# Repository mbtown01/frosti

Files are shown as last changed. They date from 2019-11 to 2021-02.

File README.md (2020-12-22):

# FROSTI

FROSTI (the Financially Responsive Open-Source Thermostat Initiative) is a
Raspberry Pi-based thermostat that monitors the current price of power on
the electric grid and changes temperature targets to minimize power usage 
during periods of high prices.

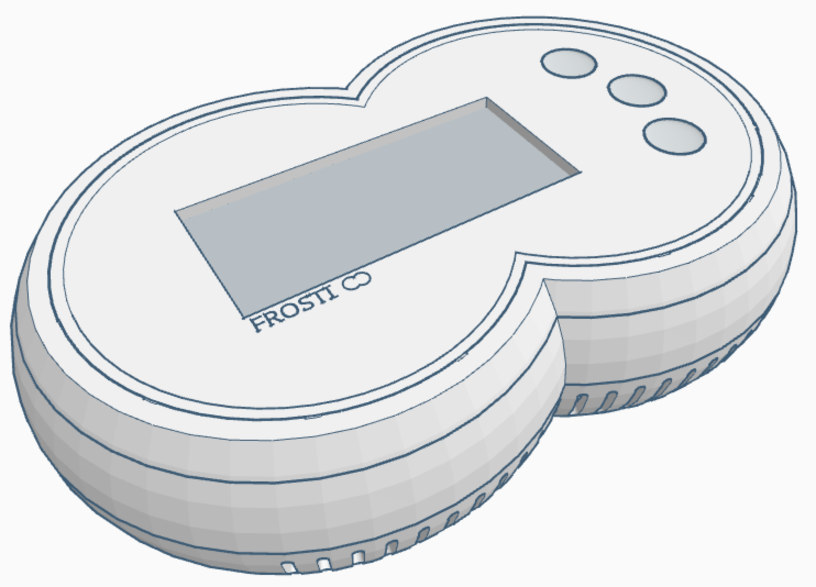
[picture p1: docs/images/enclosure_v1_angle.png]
rendering


## Features

* Real-time monitoring of local power-price
* Web-based configuration
* 2.9" e-paper display clearly visible from a distance
* LED indicators for mode changes
* Full RESTful API for monitoring status and controlling from remote

## Links

[FROSTI main site](https://mbtown01.github.io/frosti/)

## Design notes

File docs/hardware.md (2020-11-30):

---
layout: post
title: Hardware
---

At the heart of this project is the circuity that attaches to the
Raspberry Pi and hosts the extra elements that make the thermostat work.

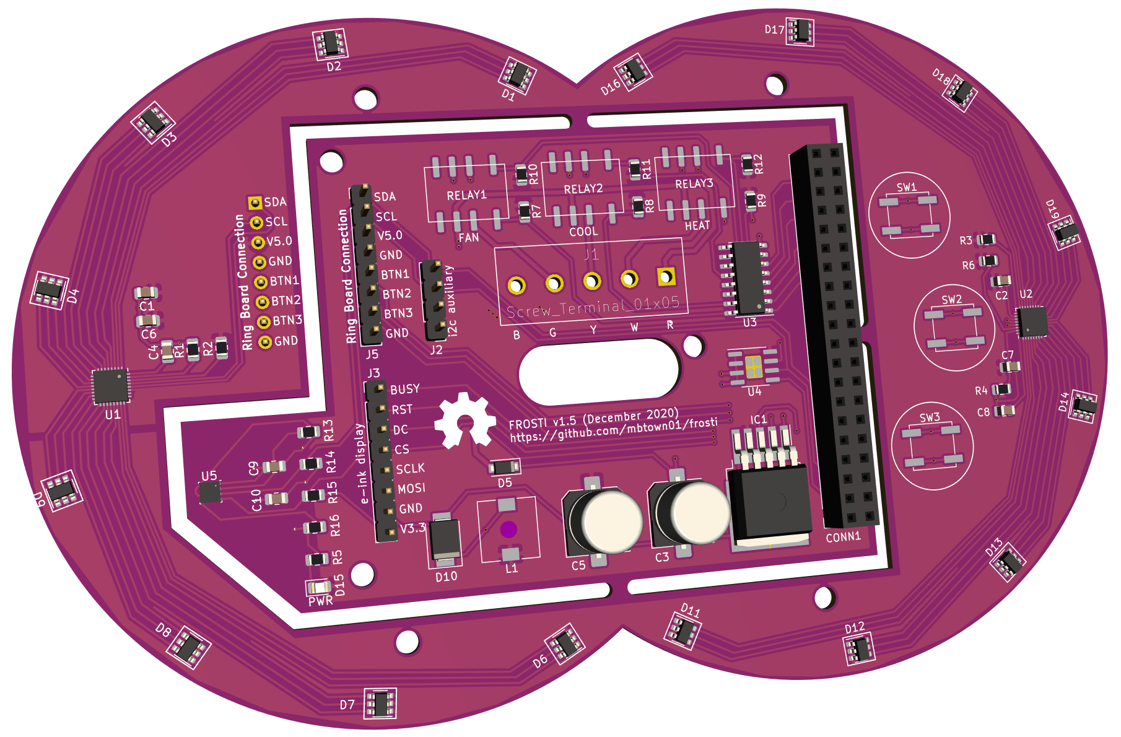
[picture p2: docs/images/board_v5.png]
board v5 rendering


The board integrates the following components:

* 24V AC to 5V DC transformer circuit
* Relays for A/C, heat and fan (simple 5-wire)
* Header for the e-paper display (Waveshare 2.9" with partial update)
* Two partial rings of 8 multi-color LEDs, each controlled w/ an LP5024
  LED driver chip for high-frequency dimming and color mixing
* BME280 environment sensor, capturing temperature, pressure and humidity
* A CAT24C256 for i2c-based storage (a component I have some ideas for
  but honestly have no clue for sure what I'll do with!)

The board is actually two boards, that after being assmebled are detached and
installed in different locations.

## Main Board

Internally there are two PCBs -- the main board containing the power
conversion circuit, thermostat relays, and the Raspberry Pi header.  It 
also contains the environment sensor, which may need to be relocated depending
on the thermals inside the case.

### Thermostat connection

FROSTI runs on the standard "5-wire" thermostat configuration, with the
following connections:

* Blue -- Common ground
* Green -- Return to power **fan**
* Yellow -- Return to power **A/C**
* White -- Return to power **heat**
* Red -- Thermostat 24V power input

The main board has a 5-port screw terminal, with the 1st letter of the wire
color labeled for installation.  

## Ring Board

The ring board is a breakout board containing all the LEDs for the UI.

This transparent rendering will give a feel for what the insides look like.

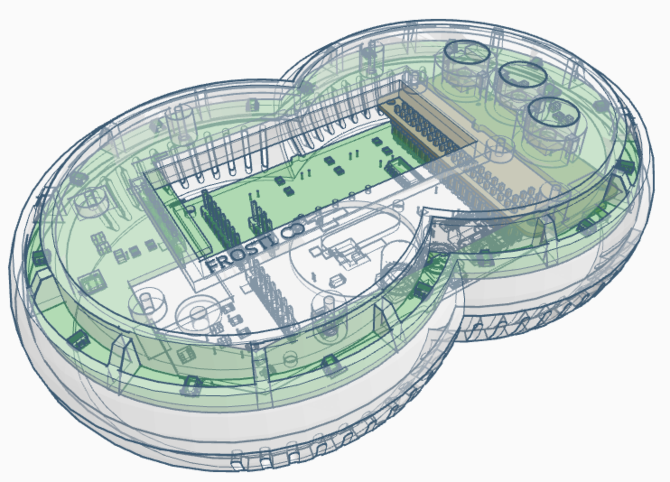
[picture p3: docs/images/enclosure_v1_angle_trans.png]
rendering


## Credits

I'd like to thank  Rays Hobby for a [great write-up on 24V AC to 5V DC power
conversion](https://rayshobby.net/wordpress/24vac-to-5vdc-conversion/).  I
personally run Ray's [OpenSprinkler Pi (OSPi)
platform](https://opensprinkler.com/product/opensprinkler-pi/) (with the 8-zone
extender!) and was inspired to take a shot at my own board by reading his blog
posts.

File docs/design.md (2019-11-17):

# Design

I kicked the idea of building a simple thermostat around for a few years.  My first iteration was a C++/Qt thermostat with a nice LCD touchscreen.  But since the RaspberryPi isn't the best _development_ environment, that quickly turned into a rabbit hole of C++ cross-compiling and libc compatibility, and don't get me started on the LCD display.

Picking the project up again in September, I took a more 'agile' approach and embraced an MVP that had a working hardware/software combination to get something *working*!  From there, we can refine.  So with that in mind, I started over in python.

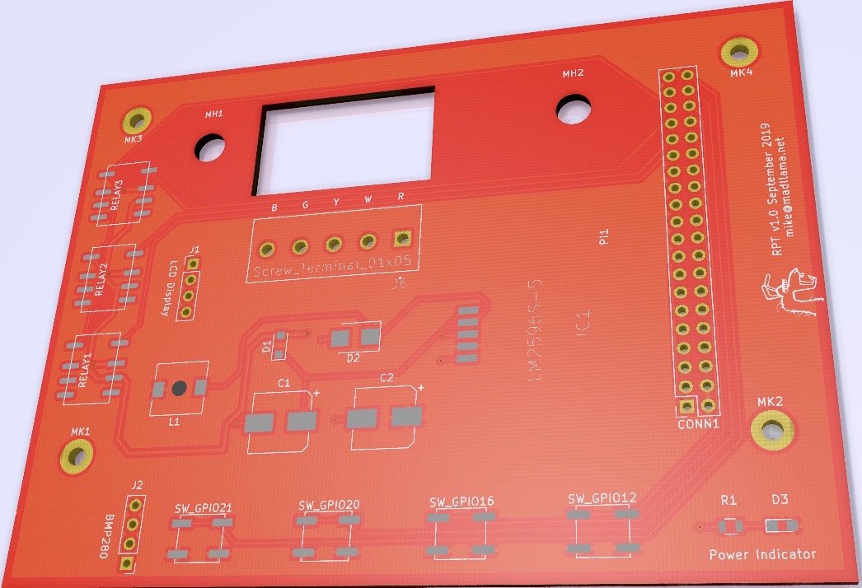
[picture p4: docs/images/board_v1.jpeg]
RPT board v1.0 rendering


The board is very simple, integrating:
* 24V AC to 5V DC power conversion
* RaspberryPi Zero W
* Three independent relays (cooling, heating, and fan)
* 20x4 character-based LCD
* 5-way temminal block to host the 5-wire thermostat cable
* 4 buttons for user input
* 2 I2C headers for the temperature sensor (BMP280) and the LCD

This is board v1.0, and there are many things that absolutely need to be changed.  I intend on writing an entire article on what I learned by running this board for a period of time and what will go into v2.0.

I'd like to thank Ray at Rays Hobby for a [great write-up on 24V AC to 5V DC power conversion](https://rayshobby.net/wordpress/24vac-to-5vdc-conversion/).  I personally run Ray's [OpenSprinkler Pi (OSPi) platform](https://opensprinkler.com/product/opensprinkler-pi/) (with the 8-zone extender!) and was inspired to take a shot at my own board by reading his blog posts.

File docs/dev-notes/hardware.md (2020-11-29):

# Hardware notes

## Simulator for Relays

After a few mis-steps, I learned that you need to give the relays more power
to move than GPIO is able to deliver.  We're employing a 'Darlington array'
(the TI ULN2003AD chip) to *briefly* deliver about 95mW to the relay.

The code below can be pasted into the circuit simulator at
<https://www.falstad.com/circuit/> to simulate the relay circuit.  The resistors
we're using (Mouser part 667-ERJ-P06F64R9V) can dissipate up to 500mW, which
this circuit will get to about 80% to move the relay.  In code, we ensure this
loop is only active for a fraction of a second.

```
$ 1 0.000005 10.20027730826997 50 5 43
r 368 272 368 160 0 64
r 224 272 224 160 0 64
r 368 272 224 272 0 90
w 224 160 368 160 0
v 128 352 128 160 0 0 40 5 0 0 0.5
w 128 160 224 160 0
s 224 272 224 352 0 1 false
s 368 272 368 352 0 1 false
w 128 352 224 352 0
w 224 352 368 352 0
```

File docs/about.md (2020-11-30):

---
layout: page
title: About
permalink: /about/
---

FROSTI (the Financially Responsive Open-Source Thermostat Initiative) is a
Raspberry Pi-based thermostat that monitors the local spot market for power
and changes temperature targets to minimize power usage during periods of
high prices.

rendering

## Features

* Real-time monitoring of local power-price
* Web-based configuration
* 2.9" e-paper display clearly visible from a distance
* LED indicators for mode changes
* Full RESTful API for monitoring status and controlling from remote

Today, FROSTI works with [GoGriddy](https://www.gogriddy.com/), but can
be extended in the future for other power markets.

## Motivation

I love the idea of having electricity priced based on supply/demand. It wasn't
long after a few friends told me about [GoGriddy](https://www.gogriddy.com/)
that I signed up.  Starting in January of 2019, I was easily saving 20% or so
relative to available electricy plans. Everything was going according to plan.

Then in August of 2019, Houston (where I live) experienced record heat combined
with electricity generation capacity shortages, causing massive spikes in
prices.  There were several times that month where prices got to $9/kW\*h,
costing me around $100 in a *single hour*.

My motivation is very simple.  Air conditioning is by far my biggest source
of power consumption.  If I can curtail usage during periods of high prices,
I get the benefits of cheap power 99.95% of the time and de-risk the other
0.05%, and I come out a winner.

## Future Work

FROSTI is about far more than just lowering your power bills.  The *data* that
comes from FROSTI is valuable for things like:

* Sizing a next A/C system (e.g. how many 'tons')
* Knowing whether your A/C system is
  [short-cycling](https://www.google.com/search?q=what+is+short+cycling)
* Knowing how changing your temperature targets affects HVAC usage

Also, with the addition of remote sensors, we could do things like:

* Balance HVAC for additional rooms
* Monitor the temperature of air coming out of the ducts, potentially catching
  problems
* Monitor the air speed at the ducts, potentially notifying the homeowner that
  airflow is impeded (e.g. filter needs changed)

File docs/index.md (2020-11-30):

---
# Feel free to add content and custom Front Matter to this file.
# To modify the layout, see https://jekyllrb.com/docs/themes/#overriding-theme-defaults
layout: home
---

FROSTI (the Financially Responsive Open-Source Thermostat Initiative) is a
Raspberry Pi-based thermostat that monitors the local spot market for power
and changes temperature targets to minimize power usage during periods of
high prices.

Today, FROSTI only works with [GoGriddy](https://www.gogriddy.com/), but can
be extended in the future for other markets where end-users are billed.

rendering

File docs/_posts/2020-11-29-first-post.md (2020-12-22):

---
layout: post
title:  "Progress towards hardware v1.5"
date:   2020-11-28 07:29:48 -0500
categories: update
---

This project has been going on in some form since the summer of 2019, and I'm
now finally getting around to blogging about it.  My goal here is to
keep some kind of a history of issues encountered and overcome, as well as
technology choices (and how that choice panned out!)

My main has recently been finalizing hardware v1.5 and an enclosure (latest
rendering below)

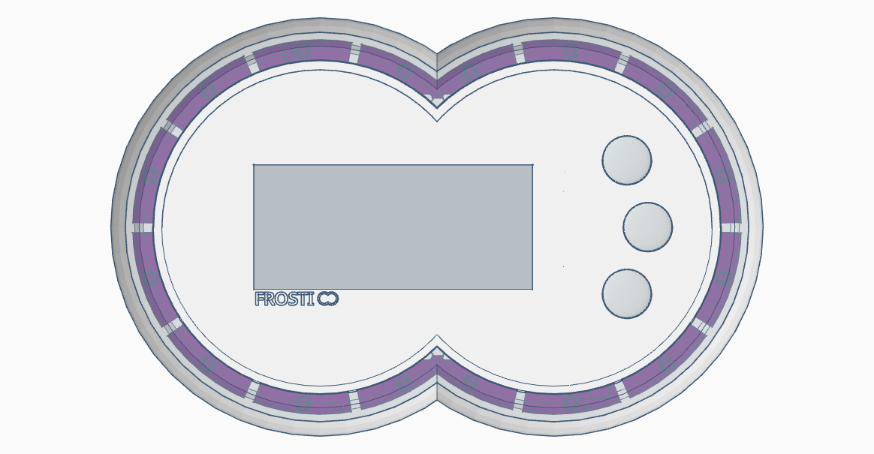
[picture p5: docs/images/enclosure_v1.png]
enclosure v1 rendering


The main (gray) rectangle outlines the location of the e-paper display I'll
be using for general status, and the three gray circles are buttons.  The
purple ring is actually the PCB visible through what will eventually be
a separately printed *translucent* cover that will scatter the light coming
from the 16 LEDs (8 in each ring) used for status indication.

The actual PCB I put together (which is as close to [OSHPark](http://oshpark.com)
purple I could get!) is below

board v5 rendering

Included in hardware v5 will be:

* 24V AC to 5V DC transformer circuit
* Relays for A/C, heat and fan (simple 5-wire)
* Header for the e-paper display (Waveshare 2.9" with partial update)
* Two partial rings of 8 multi-color LEDs, each controlled w/ an LP5024
  LED driver chip for high-frequency dimming and color mixing
* BME280 environment sensor, capturing temperature, pressure and humidity
* A CAT24C256 for i2c-based storage (a component I have some ideas for
  but honestly have no clue for sure what I'll do with!)

## Next steps

I have ordered a PRUSA "mini" 3d printer and it should be arriving in the
next week or two.  You can be sure I'll have several updates on what I learn
as part of doing some of my first 3d prints!

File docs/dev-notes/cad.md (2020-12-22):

# CAD and 3d Printing

Some references I've found on the web that are helpful when designing the
case:

* <https://ultimaker.com/en/resources/52843-design-guidelines>

## KiCAD tips/tricks

Export a BOM for Mouser

* Use the bom2grouped_csv plugin
* cut -d, -f2,7 thermostat | sed "s/\"//g" | grep -v "^[0-9],*$" | grep -v MPN | sed "s/\(.*\),\(.*\)/\2 \1/"
* Use mouser's BOM import tool, paste in the text generated above

## Looking at both board and model simultaneously

* Export as VRML (with mm as units) from Kicad
* Use <https://www.makexyz.com/convert/wrl-to-stl> to convert to STL
* Import directly into Tinkercad

## Tips and tricks for 3d design of printed parts

* <https://www.3dhubs.com/knowledge-base/enclosure-design-3d-printing-step-step-guide/>
* <http://infocenter.3dsystems.com/bestpractices/mjp-best-practices/projet-mjp-2500/snap-fits>

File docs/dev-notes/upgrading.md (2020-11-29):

# Upgrading the thermostat

```bash
# Upgrade docker-compose
sudo pip uninstall docker-compose
sudo pip install docker-compose
```

```bash
# Pull the latest images
docker-compose --file docker/docker-compose-arm.yaml pull
```

You may want to backup the database as well

sudo systemctl daemon-reload
/etc/systemd/system/frosti.service

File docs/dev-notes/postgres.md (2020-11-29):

# Working with postgres

## Get some data for development work

The scenario is that you have a thermostat in production and want to grab some
data from it to use locally. First, get a terminal in the postgres container:

```bash
docker exec -ti frosti-daemon bash
```

From there, grab the data from the running thermostat you're interested in and
place it in the local docker-compose postgres instance 'postgres':

```bash
# Extract info from a specific thermostat
pg_dump --host pi-frosti-h1.local.madllama.net \
    --username frosti frosti \
    --create --schema=public --clean  > /tmp/dump.dat
# Drop the existing schema if it exists
psql \
    --host postgres \
    --command='drop schema public cascade' frosti frosti
# Import the data AND SCHEMA
psql \
    --host postgres \
    --file /tmp/dump.dat frosti frosti
```

## Upgrading schemas

When a non-trivial change to the postgres schema happens, I've created an
'upgrade-db.py' script to facilitate things outside the normal execution
path of the thermostat logic. It simply moves the existing schema over to
another name and does internal SELECT INTO statements to massage the data
and populate the new schema.

```bash
PYTHONPATH=. ./scripts/upgrade-db.py --finalize
```

## Fun queries

Process the thermostat state log and show event durations

```sql
select
    time as endingTime,
    delta,
    delta*lastCooling as coolingSeconds,
    delta*lastHeating as heatingSeconds,
    delta*lastFan as fanSeconds
from (
    select
        time,
        lag(cooling) over (order by time) as lastCooling,
        lag(heating) over (order by time) as lastHeating,
        lag(fan) over (order by time) as lastFan,
        extract(epoch from time-lag(time) over (order by time)) as delta
    from thermostat_state
    ) as foo
```

Show how many times the thermostat skipped a reasonably
long temperature check over the past 30 days, possibly 
because it had frozen and needed a reboot
```sql
select
    *
from (
    select
        time, time - lag(time) over (order by time) as delta
    from sensor_reading
    where time > NOW() - INTERVAL '30 DAYS'
    ) as foo
where extract(epoch from foo.delta) > 60
```

Calculate the percentage of time we spend cooling over the past 24 hours

```sql
select
    NOW() as time, sum(delta*lastCooling)/3600.0/24.0 as percentCooling
from (
    select
        lag(cooling) over (order by time) as lastCooling,
        extract(epoch from time-lag(time) over (order by time)) as delta
    from thermostat_state
    where time > NOW() - INTERVAL '1 DAY'
    ) as foo
```

Calculate the percentage of time we spend cooling over the past 24 hours

```sql
select
    min(foo.time) as time, avg(foo.delta)/60.0 as "average cycle time"
from (
    select
        time,
        lag(cooling) over (order by time) as lastCooling,
        lag(heating) over (order by time) as lastHeating,
        extract(epoch from time-lag(time) over (order by time)) as delta
    from thermostat_state
    ) as foo
where
  foo.time BETWEEN '2020-05-20T15:26:45.498Z' AND '2020-05-20T18:26:45.498Z'
  and lastCooling + lastHeating > 0
group by
  floor(extract(epoch from foo.time)/60)*60
```

Old query grouping by minute that AVERAGES when we really want LAST_VALUE

```sql
SELECT
  floor(extract(epoch from "time")/60)*60 AS "time",
  max(comfort_max) AS "comfort_max"
FROM thermostat_targets
WHERE
  "time" BETWEEN '2020-05-19T18:53:14.694Z' AND '2020-05-20T18:53:14.694Z'
GROUP BY 1
ORDER BY 1
```

New query

```sql
select
    floor(extract(epoch from bar.time)/60)*60 AS "time",
    max(bar.comfort_max) AS "comfort_max"
from (
    select
        time,
        last_value(comfort_max)
        over (
            partition by floor(extract(epoch from time)/60)*60
            order by time
            range between unbounded preceding and unbounded following
        ) comfort_max
    from
        thermostat_targets
    union
    select
        '2020-05-20T08:20:33.914Z' as time,
        last_value(comfort_max)
        over (
            order by time
            range between unbounded preceding and unbounded following
        ) comfort_max
    from
        thermostat_targets
    WHERE
        "time" < '2020-05-20T08:20:33.914Z'
) bar
WHERE
    "time" BETWEEN '2020-05-20T08:20:33.914Z' AND '2020-05-20T20:20:33.914Z'
GROUP BY 1
ORDER BY 1
```

```sql
select
    NOW() as time,
    avg(delta*lastCooling)/60.0 as "average cycle time"
from (
    select
        lag(cooling) over (order by time) as lastCooling,
        extract(epoch from time-lag(time) over (order by time)) as delta
    from thermostat_state
    ) as foo
where
    lastCooling > 0
```

```sql
select
    measurement, bucket, count(bucket)
from (
    select
        NOW() as time,
        measurement,
        round(delta*value/60)*1 as bucket
    from (
        select
            'cooling' as measurement,
            lag(cooling) over (order by time) as value,
            extract(epoch from time-lag(time) over (order by time)) as delta
        from thermostat_state
        where time > NOW() - INTERVAL '1 DAY'
        union
        select
            'heating' as measurement,
            lag(heating) over (order by time) as value,
            extract(epoch from time-lag(time) over (order by time)) as delta
        from thermostat_state
        where time > NOW() - INTERVAL '1 DAY'
        ) as foo
    where
        value > 0
) as bar
group by
    measurement, bucket
order by
    bucket
```

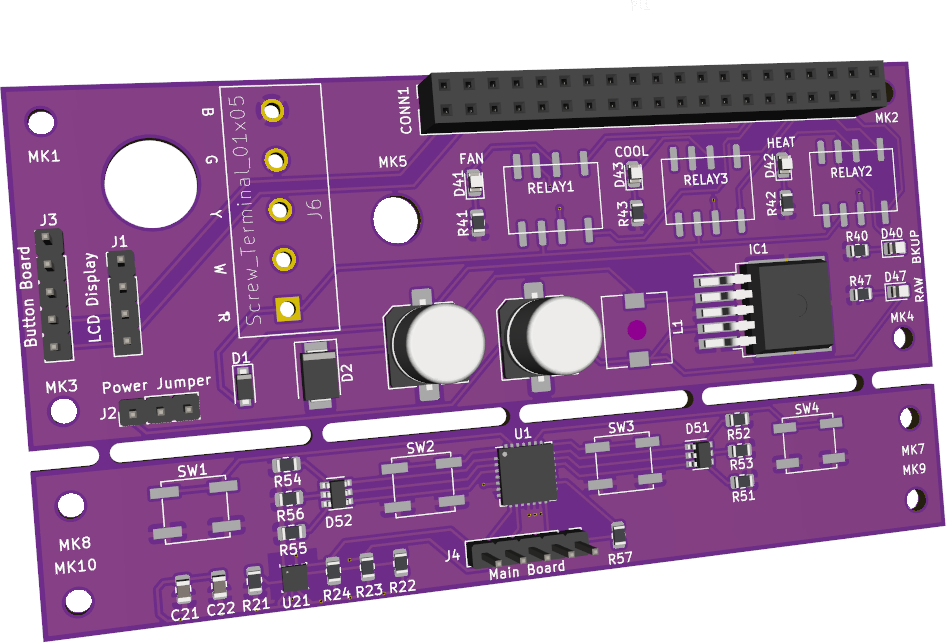
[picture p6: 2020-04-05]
docs/images/board_v4.png

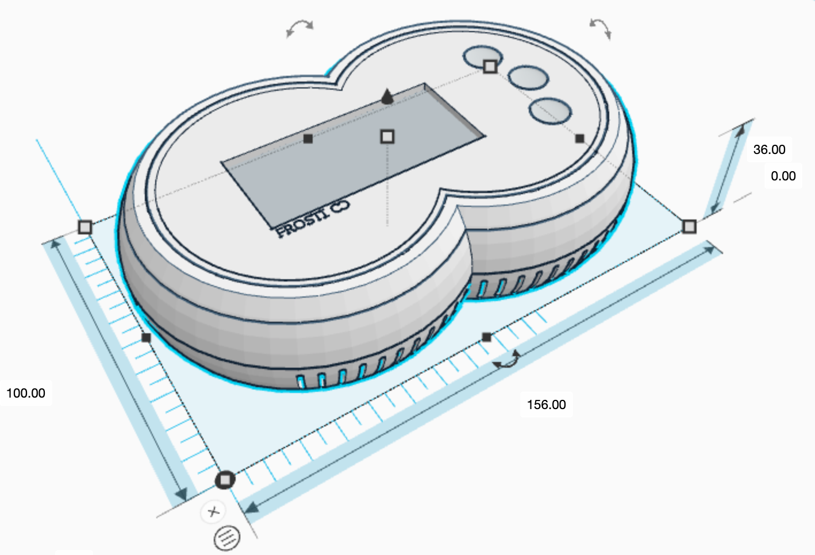
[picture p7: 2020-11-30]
docs/images/enclosure_v1_dimensions.png

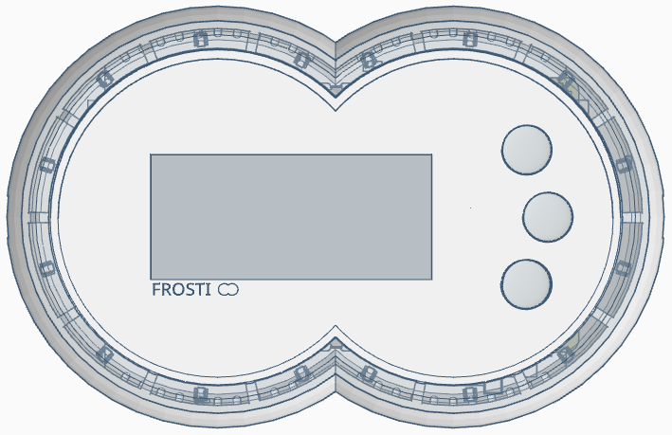
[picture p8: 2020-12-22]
front.png

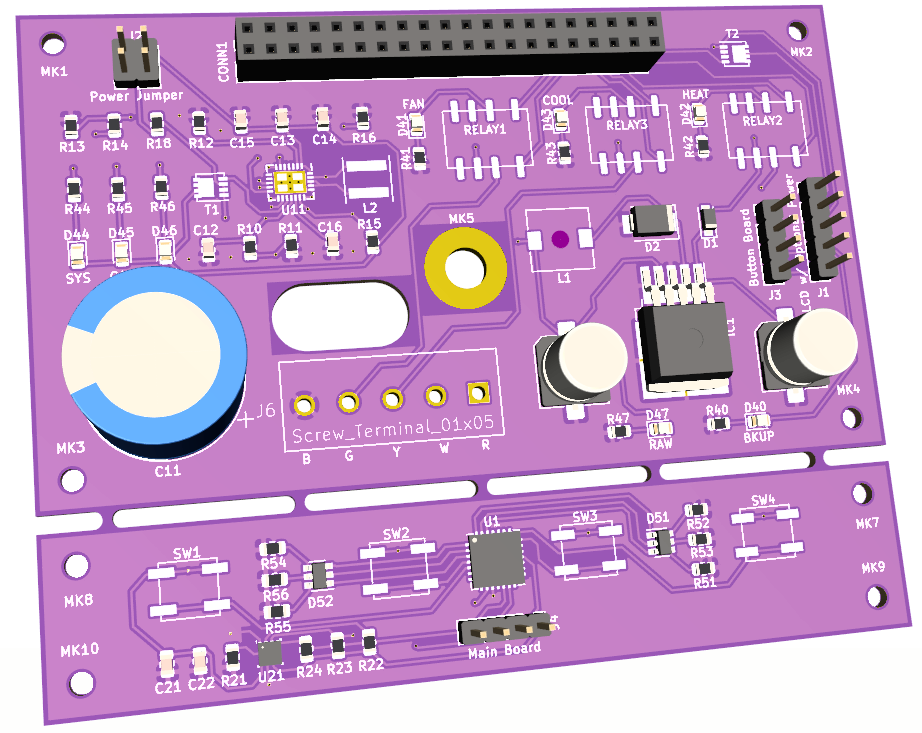
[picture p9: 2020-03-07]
docs/images/board_v3.png

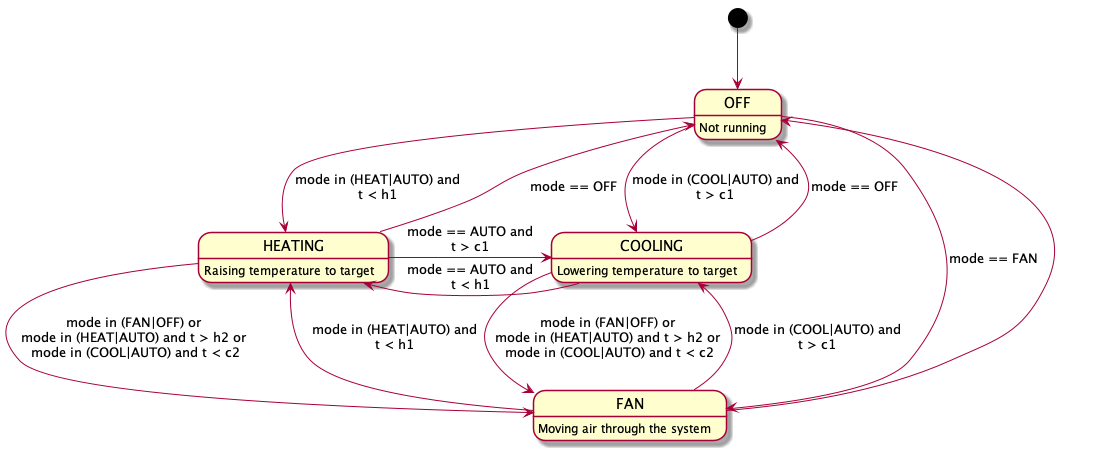
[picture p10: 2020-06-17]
docs/diagrams/ThermostatStates.png

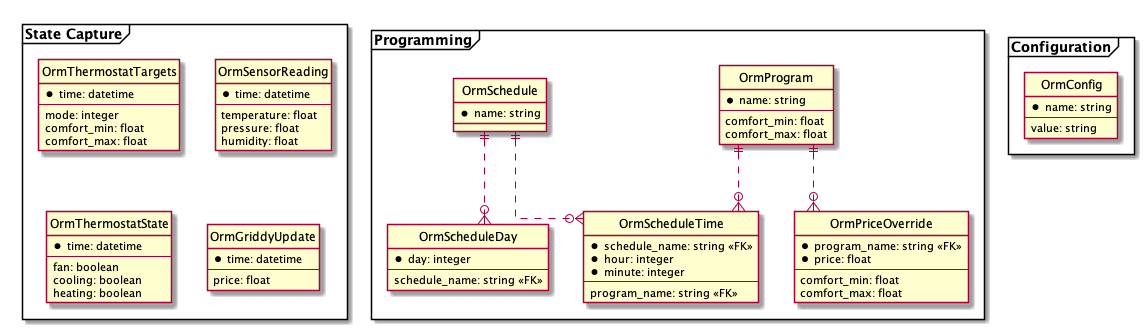
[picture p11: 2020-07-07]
docs/diagrams/ObjectRelationalModel.png

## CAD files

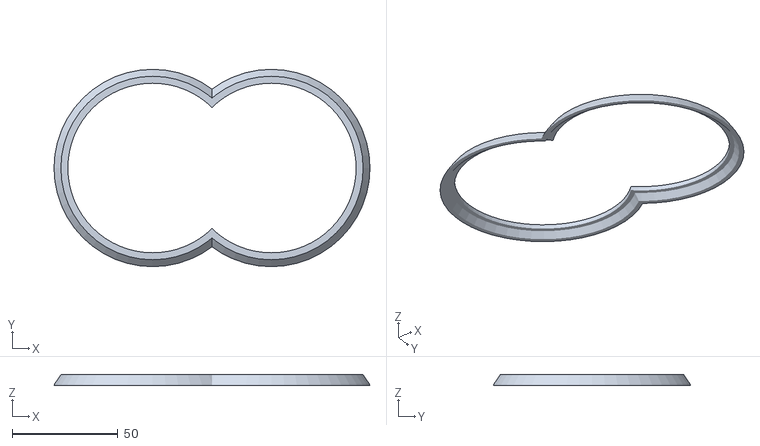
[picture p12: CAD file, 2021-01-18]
hardware/enclosure/diffuser.stl
149.1 x 93.1 x 4.99

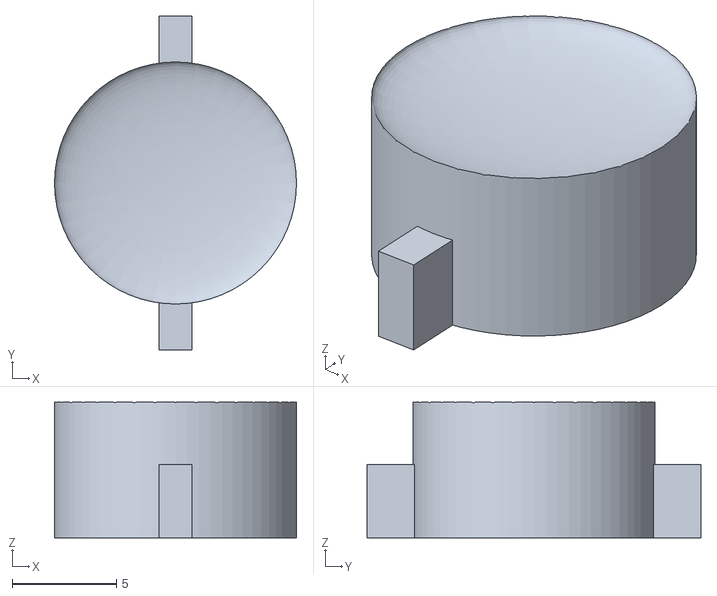
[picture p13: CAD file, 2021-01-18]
hardware/enclosure/button.stl
11.6 x 16.0 x 6.50

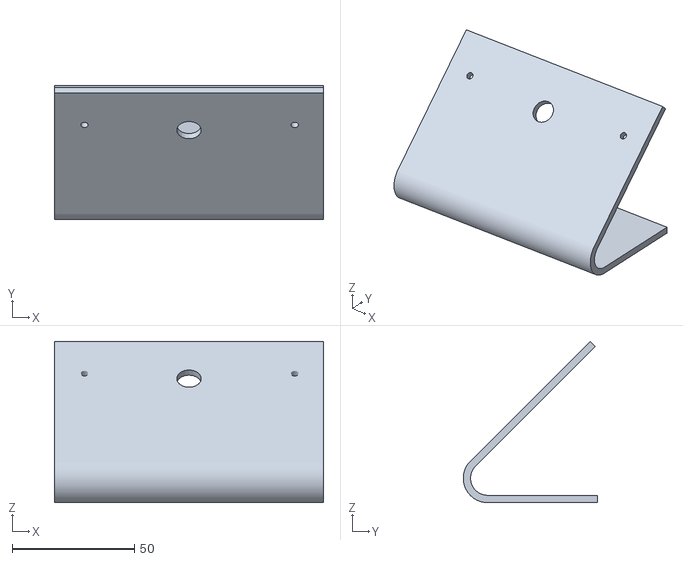
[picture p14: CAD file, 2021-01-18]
hardware/enclosure/kickstand.stl
110.0 x 55.0 x 66.0

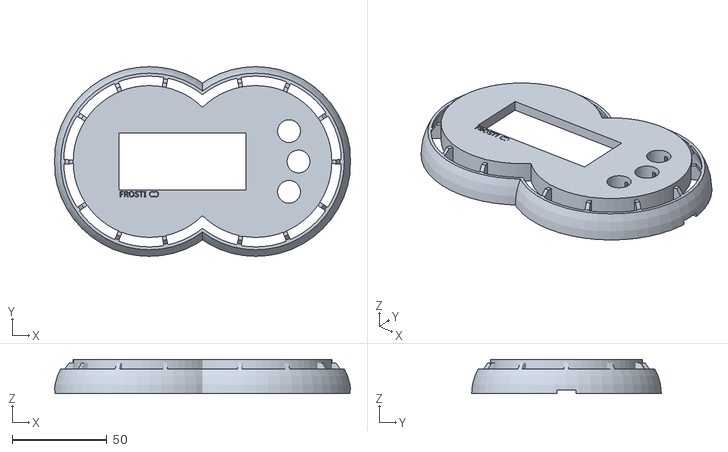
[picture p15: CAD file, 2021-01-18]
hardware/enclosure/top.stl
156.0 x 100.0 x 18.0

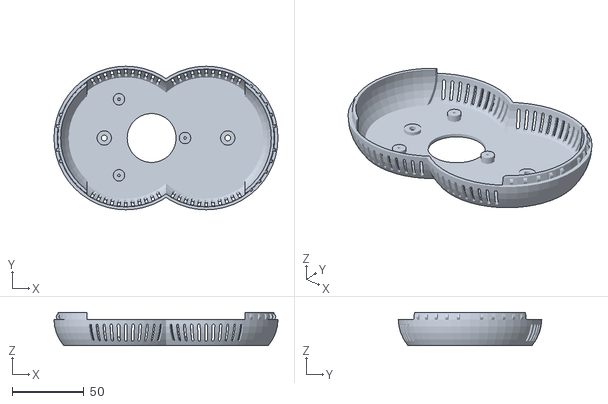
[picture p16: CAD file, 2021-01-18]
hardware/enclosure/bottom.stl
156.0 x 100.0 x 23.0

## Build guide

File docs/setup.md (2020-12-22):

---
layout: page
title: Developer Setup
permalink: /setup/
---

## Getting Started

```bash
git clone https://github.com/mbtown01/frosti.git
```

You'll need to install docker and docker-compose.

> Before we go further here, it's important to note that for Linux-based dev
> setups, your distribution's version of docker may not be the latest. If the
> commands below don't work, be sure docker's version is >= 1.26. For Ubuntu,
> the following [guide](https://www.digitalocean.com/community/tutorials/how-to-install-and-use-docker-on-ubuntu-18-04) helped me.
>
> You will also need docker-compose, which oddly enough doesn't come with the
> Linux distribution (though it does seem to come w/ the Windows one?) I would
> checkout this [guide](https://docs.docker.com/compose/install/) on how to do
> that. On the raspberry pi you may also need to check out [another guide](https://dev.to/rohansawant/installing-docker-and-docker-compose-on-the-raspberry-pi-in-5-simple-steps-3mgl)

Even though the Raspberry Pi is our target platform, almost all development
starts on x86 systems. For this guide, I'll refer to `${ARCH}` which can
be either `x86_64` or `arm` depending on the context.

Once you have the source pulled down and the latest version of docker, let's
bring up the development environment for the first time:

```bash
docker volume create grafana-data
docker volume create postgres-data
docker-compose --file docker/docker-compose-${ARCH}.yaml up -d frosti-dev
```

> _Fun fact -_ You can build and push your arm images from x86_64!

The process above is is pulling down the latest docker images for the project
and running them locally. Later on we'll discuss how to build those images
locally.

Once completed, we can test if it worked by running the thermostat simulator
from a terminal inside the dev environment:

```bash
docker exec -ti frosti-dev bash
python3 -m frosti --hardware term
```

If the above worked, **congrats** -- you now have a local copy of the source
code and a container setup to run it in. You can tweak the code and re-run the
command above to test your changes.

> _Fun fact -_ Tell Docker to only use one core on your laptop! That will
> save you a ton of battery!

## Microsoft VSCode

Once you have VSCode installed and before you load the project for
the first time, install the following extensions:

- Python (Microsoft)
- Remote - Containers (Microsoft)

Next, start a development container on the local machine as we did above:

```bash
docker-compose --file docker/docker-compose-${ARCH}.yaml up -d frosti-dev
```

Now, instead of opening the project directly from your local cloned workspace,
click the bottom-left-hand corner in the IDE and chose "Remote-Containers:
Attach to Running Container". From there, choose 'frosti-dev'. This should start
a new copy of VSCode that is now "inside" your running development container.

Once in the container, it will take a minute or to do to its initial setup.
You'll then want to open the folder '/usr/local/frosti' which is where the source
code is. You will likley need to install/enable the Python module again in
this copy of VSCode (beacuse it's in the container). I also recommend saying
'yes' to all the prompts you'll get for installing a linter, the testing
libraries, etc.

From here, you **should** be able to debug using the 'Local fake hardware'.
Most of the above I figured out from the following [documentation](https://code.visualstudio.com/docs/remote/containers)

> I've had some issues recently where VSCode is trying to interpret the
> locale and gets it wrong. The sympton is when you start a debug session but
> you get a bunch of errors about locale settings. [This bug
> report](https://github.com/microsoft/vscode-remote-release/issues/2169)
> explains the fix (spoiler alert: Turn off 'Detect Locale' in the integrated
> terminal in VSCode settings)

### Debug/attach on RaspberryPi

The configuration above works well for a x64 workstation doing
terminal-based work. However, when developing on the RaspberryPi, you're
going to want to still run the IDE on a big machine and then use the
'Remote-SSH' plugin to get to the Pi. Once installed, click the
lower-left-hand corner quick menu and select 'Remote-SSH: Connect to
Host...' and choose the pi you're working on.

Once there, you can clone the github repo, build (or pull) the arm-based
rpi container, and you're off! If you want to debug your code interactively
with VSCode, first open a local terminal and start python under the debugger:

```bash
docker-compose --file docker/docker-compose-arm.yaml up frosti-debug
```

Once the above is complete, you should be able to choose the 'Python: Local
Attach' debug profile and start debugging. 'Local Attach' is configured in
.vscode/launch.json to run on the local host and has the source directory
mappings configured so the debugger can step line-by-line.

## Building images locally

By and large, the only changes at development time are in the code, which do
not require the container images to be re-built. However, sometimes there is
a need to update the images. When that time comes, we rely on regular
`docker build` (and not `docker-compose`):

```bash
# Build grafana on x86_64 (starting on the repository root)
docker build --tag mbtowns/grafana:x86_64-latest -f docker/grafana/Dockerfile.x86_64 docker/

# Build the x86 development environment
docker build --build-arg FROSTI_DEV=true--no-cache -f docker/frosti/Dockerfile.x86_64 docker/
```

## QEMU / Build Raspberry Pi Images on x64

I followed [these
instructions](https://matchboxdorry.gitbooks.io/matchboxblog/content/blogs/build_and_run_arm_images.html)
and magically built the frosti container for arm on my local x64 linux box.
Good in a pinch, but I think an RPi v4 is probably faster...

In summary, when the base image coming from an arm-based container, docker
seems to realize this and know that it needs emulation should you be
building on an non-arm platform. It then looks for /usr/bin/qemu-arm-static
(which we inject in to the container).

In summary, on `x86_64` platforms you can simply refer to the `arm` Dockerfile
and docker-compose files and it should simply work. This is much faster than
building on the Raspberry Pi Zero, though a Raspberry Pi v4 makes it much
faster.

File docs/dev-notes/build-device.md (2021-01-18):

# Start a new Raspberry Pi from scratch

## Download the image

Before going anywhere, let's go get the latest version or raspbian from
the Raspberry Pi foundation

[https://www.raspberrypi.org/downloads/raspbian/](https://www.raspberrypi.org/downloads/raspbian/)

## Thoughts on an image builder service

- Could host a simple service that builds images, taking a stock image
  and doctoring it just enough to be useful at first boot
- User presented with some simple question/answers
  - WiFi network SSID/password
  - Host and frosti SSH keys
  - Version of FROSTI to start with from github releases/tags
- Using info above, installer would mount the pure Raspberry Pi OS image, and
  boostrap the installer process with the parameters above
  - This may be necessary to create the 3rd read/writeable partition
- This COULD even be a feature of FROSTI, depends on how much space an SD
  card has

## Order operations

- Image builder
  - Gets user input on wifi ssid and password
  - Gets user input on hostname (w/ a default)
  - Creates the intial image
  - Removes the automatic '/' filesystem expansion
  - Adds the startup logic
  - (any other misc update to the base image before first install)
- First startup
  - Configure wireless network
  - Download **core** packages
  - Install FROSTI source
    - Ideally here we'd have enough at this point to start using the CLI to
      give notification to the user that things are happening
      Install the rest of the packages
  - File systems
    - Expand '/' to 3GB
    - Create new '/data' partition
    - Create an in-memory tmpfs for logs and then setup logs to not be
    - so chatty
    - Figure out how to make '/' read-only

## Using Raspbian installer

To setup a new SD card from scratch using Raspbian installer, follow the
following process:

- Burn an image of Raspberry Pi OS "Lite" to an SD card
- Boot the PI and immediately configure your network so ou can talk w/ the
  outside world (this is probably on necessary if you need to use Wifi, a
  wired connection should already just work)

```bash
sudo raspi-config nonint do_wifi_ssid_passphrase 'ssid' 'passphrase'
```

Now just go install stuff...

```bash
curl -fsSL https://raw.githubusercontent.com/mbtown01/frosti/master/scripts/setup.sh | sudo bash -
```

## Using build-image.py

In my example below, I've downloaded and will use
~/Downloads/2020-02-13-raspbian-buster-lite.img as my base image. Notice that
we're using the 'lite' image -- no reason to download a full desktop.

Once downloaded, unzip it to get the actual image out

```bash
unzip ~/Downloads/2020-02-13-raspbian-buster-lite.zip
```

To simplify things, we've built a simple scrip that will take the img file
and tweak it so that the raspberry pi that uses it is immediately bootable.
When it boots, the device _should_ come up on the wireless network and be
open for ssh connections for user 'pi'. The 'pi' account is seeded with the
ssh public key of the user passed to the script.

```bash
sudo ./scripts/build-image.py \
    --image ~/Downloads/2020-02-13-raspbian-buster-lite.img \
    --hostname ${YOUR_HOST_NAME} \
    --user ${LOCAL_USER_WITH_SSH_PUB_KEY} \
    --ssid ${YOUR_SID} \
    --passwd ${YOUR_PASSWD}
```

Now we have an image ready to be placed onto an SD card. There are tons of
resources on-line to show more details about how to do this. The 'lsblk' and
'lsusb' commands can be used to help identify your local SD card device mount.

```bash
sudo dd \
    if=~/Downloads/2020-02-13-raspbian-buster-lite.img \
    of=${YOUR_DEVICE} \
    bs=4M \
    conv=fsync
```

## Configuration

Once the image is booted, it now needs to be configured. Let's ssh in and
take a look around. As the user you specified to the build-image.py script
above, you should now be able to:

```bash
ssh pi@${YOUR_HOST_NAME}
```

We're using Ansible to largely automate the rest of the configuration. To
get there though, we'll have to manually install it

```bash
sudo apt update && sudo apt upgrade -y --fix-missing
sudo apt install -y ansible git i2c-tools vim
```

```bash
cd /usr/local && sudo git clone https://github.com/mbtown01/frosti.git
```

```bash
ansible-playbook etc/ansible.yaml
```

The ansible playbook does the following

- Configures the hardware watchdog to reboot if the CPU locks
- Enables i2c
- Installs docker, docker-compose, and adds use 'pi' to the docker group
- Installs the frosti daemon as a service

Once the play has completed successfully, a reboot is required. If all went
well, at reboot you'll wait a really long time while the Pi downloads and
installs the containers that frosti depends on, then builds the container for
frosti. Once that's complete, it _should_ just magically start.

## Assumptions

Once the device is up and running, we assume it can reach out to the open
internet to download updates and to check Griddy for current electricity
cost information. We also assume it can be reached on the local network
to be seen by client browsers for remote configuration.

## Future work

Should look into running the PI w/o the SD card mounted

https://mtyka.github.io/hardware/2018/10/09/read-only-pi.html#:~:text=One%20work%20around%20is%20to,makes%20it%20way%20less%20likely.

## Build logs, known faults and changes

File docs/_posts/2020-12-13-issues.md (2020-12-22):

---
layout: post
title: "3d Printing and Hardware v1.5 Update"
date: 2020-12-13 7:33:25 -0600
categories: update
---

Over the past couple weeks I've received my 3d printer and the v1.5 boards
from OSHPark and made a bunch of progress. Below is a dump of what went well
and what I've learned.

## 3D printing and enclosure design

I have to admit, I had this pre-conceived notion that 3d printing would be
easy -- just plug it in, feed some filament and go! Once I assembled the
printer [(the PRUSA Mini+)](http://prusa3d.com), I spent the next couple days
doing test prints to understand the filament I purchased and how it works with
the printer. I made one or two plastic blobs in the process, but in general I
think I know what I'm doing now.

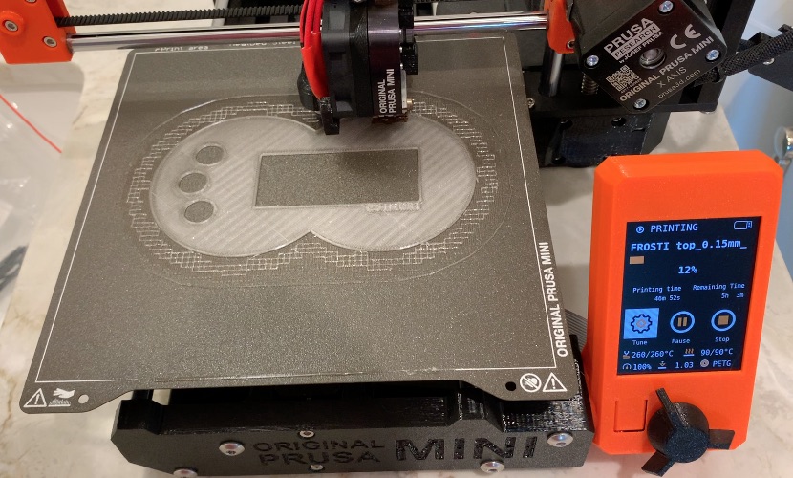
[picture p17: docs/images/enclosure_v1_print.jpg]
printing example


Some thoughts on my first case design...

- Top and bottom fit together nicely, but it's hard to determine orientation.
  We need something inside that makes it clear which side is which.
- Need a snap mechanism for the diffuser to attach it to the top
- The diffuser may need significantly more thickness to catch the light, the
  current design still clearly shows a single LED in each arc segment.

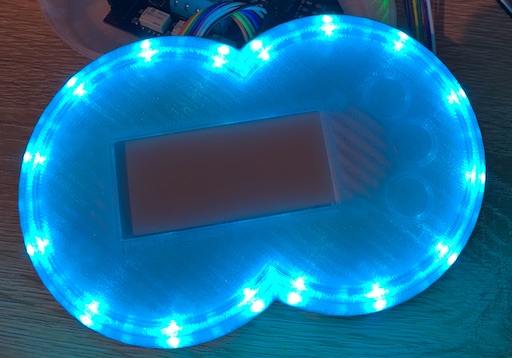
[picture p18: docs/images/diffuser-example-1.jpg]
diffuser example


## Hardware v1.5 issues

Some things went well, some things... eh, not so much. Here's the rundown:

### SMD soldering seemingly flawless

This is by far my most complicated board I've tried to assemble on my own.
The LED driver chip pins are very small and close to each other, making it
hard to get the solder paste to line up well w/ the stencil. However, after
running tests on the board, it seems like every component that went through
the reflow process connected perfectly

### Pi header orientation 180deg off

Embarrassingly enough, I somehow placed the 20x2 Raspberry Pi header backwards
in a way that prevents the Pi Zero from being directly connected. It's
somewhat understandable considering it's a perfect rectangle of 40 holes that
looks the same when rotated 180 degrees. For now, this is okay as it will
make a good development setup, but it is quite disappointing that this
prototype won't make it onto the wall...

### Hand-soldering GPIO pins creates issues

It would also seem that while hand-soldering the header I somehow got enough
solder on one of the relay control GPIOs to flow _underneath_ the header
block and bridge one of the adjacent GND pins. For the next board, I'll need
to either be lighter on the solder or find a different technique. My _guess_
is that while getting the solder close to the pin, I actually _pushed_ solder
into the hole, creating the issue.

## Next steps

For now, I'm going to move forward with this board and focus on updating the
user interface to work with the new 3-button layout, the LED light ring, and
the e-paper display. This will likely require some kind of web-based
simulator so I can run tests w/o any local hardware.

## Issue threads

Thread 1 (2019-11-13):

LCD display turns into garbage characters

mbtown01, 2019-11-13:
Seems to occur when the thermostat board closes a relay for AC or HEAT.  Solution could be as easy as some power filtering capacitors on the board

Closed 2020-05-12.

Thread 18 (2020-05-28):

Optimize grafana postgres queries

mbtown01, 2020-05-28:
Currently, we're pulling the entire window to get things like 'current temperature'.  The scalar values need to have a static window of the past say 5 minutes...  If the data isn't there, then something else is wrong.

Closed 2020-11-02.

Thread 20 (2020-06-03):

Create pre-installation checkout mode in hardware/software

mbtown01, 2020-06-03:
Need to tie relays back to GPIO inputs to track their state (either replacing or putting in-line w/ the LEDs we're currently using)

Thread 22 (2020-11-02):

Integrate e-paper display into user interface

mbtown01, 2020-11-02:
This should effectively replace the terminal-based version of the user interface.  Even for a developer experience, the UI could be exposed via a simple python window or even an HTML page  w/ some kind of refresh

mbtown01, 2020-12-15:
Create a GenericGraphicInterface that handles drawing the graphics and takes events on button inputs.   A derived class can later specialized w/ the e-paper display and the GPIO buttons.  This service should also have a method to scrape the latest display image so the API service can put up a simple webpage to show the device and present the buttons.  This should just completely replace the character-based stuff we've been doing -- just need to commit to it.

An image has been added to the root repo we can use to show the user what the device currently looks like.   Now that we're pretty committed to the current hardware design, we could have the generic service know all about the physical device and draw images of it?  Just want a web-based development experience so nobody needs to be next to a physical device to work.  Need to make sure we don't make things "uselessly generic!!"

Closed 2021-01-21.

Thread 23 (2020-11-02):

Design the thermostat enclosure

mbtown01, 2020-11-02:

mbtown01, 2020-11-03:
Some thoughts as we put the board together:

* The screen is not perfectly centered on it's substrate, will need some kind of balance as it's placed
* Do we need buttons?  And if so, where should they go??
* To whatever degree possible we should separate the air volume between where the PiZero is and where the sensors are

Closed 2020-12-15.

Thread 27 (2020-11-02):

Design board v5

mbtown01, 2020-11-02:
Item used to track feature requests for board v5

* Relay feedback via GPIO so we know we've successfully opened each relay
* Clear labels for each connection so it's obvious how to connect (includes board-to-board connections, jumpers, and even the connection to the thermostat wires to not just be color but also function)
* Diagnostic LED header so it can be enabled/disabled
* Encode a hardware 'version' somehow

Closed 2020-12-15.

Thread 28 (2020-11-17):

Grafana controls plug-in doesn't change heat properly

mbtown01, 2020-11-17:

Closed 2021-01-25.

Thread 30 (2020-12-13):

Hardware fixes

mbtown01, 2020-12-13:
* .1 and 1 uF capacitors need redistributed for power filter near the LED drivers
* the 4.8kOhm resistors are still NOT 0805?!?
* cap C10 should be grouped w/ the other .1 uF caps
* Entire RPi header is rotated 180deg

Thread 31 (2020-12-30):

Add a CLI for operating the screen and LEDs w/o running the software

mbtown01, 2020-12-30:
Use case here is for setup where the main software isn't running, but we'd like to alert the user to what's going on.  With the CLI, we can issue images to the display and operate the lights.  Ideas were:

* During setup, show progress and what the current step is
* Clear all status at boot time

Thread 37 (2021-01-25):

Redesign around stateless device

mbtown01, 2021-01-25:
Currently, the FROSTI device has a database and stores all of it's state and configuration there.

To build a more resilient device, we need to make the SD card completely read-only.  To do this, we need to at a high level:
* Remove our dependence on a database, keeping all local state in memory (with some reasonable buffer, say 1 month)
* Remove grafana from the device as it requires a database to communicate w/ the device
* Add a single-page app (hosted by the main FROSTI process) that lets the user interact with the device
* Build a back-end API that lets the device push measurements somewhere else to be analyzed

If done well, the back-end API could be on the web of hosted locally.  1st pass would just include pushing measurements so if FROSTI reboots it can pick up where it left off, even with historic data.

We can also potentially leverage the on-board EEPROM for storing things like
* A device UUID for the web API
* Last known configuration (which shouldn't take too much space, not sure if this is necessary)

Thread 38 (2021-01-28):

Integrate a Dash-based front-end

mbtown01, 2021-01-28:
Dash integration for a simple single-page app for configuration/setup

Guiding principles:
* This may be the only web-based integration a user gets (e.g. w/o backend container)
* Should some recent data, but not designed to keep all data over time, just from last boot (need back-end container)

Should expose the following:
* General configuration (things like the setup constants, time zone?? )
* Program (how many programs, when they run, how to respond to price)
* Status/Insights (some simple charts showing price/temperature)
* Controls (maybe even a web-based FROSTI w/ the buttons?!?!).

mbtown01, 2021-02-13:
Currently, we're relying on a backing web service to handle all communication between a web frontend and the thermostat logic.  With an embedded Dash app, this largely goes away.  A simple version of the API can stay around, but we should completely dump it for the time being and replace with Dash.

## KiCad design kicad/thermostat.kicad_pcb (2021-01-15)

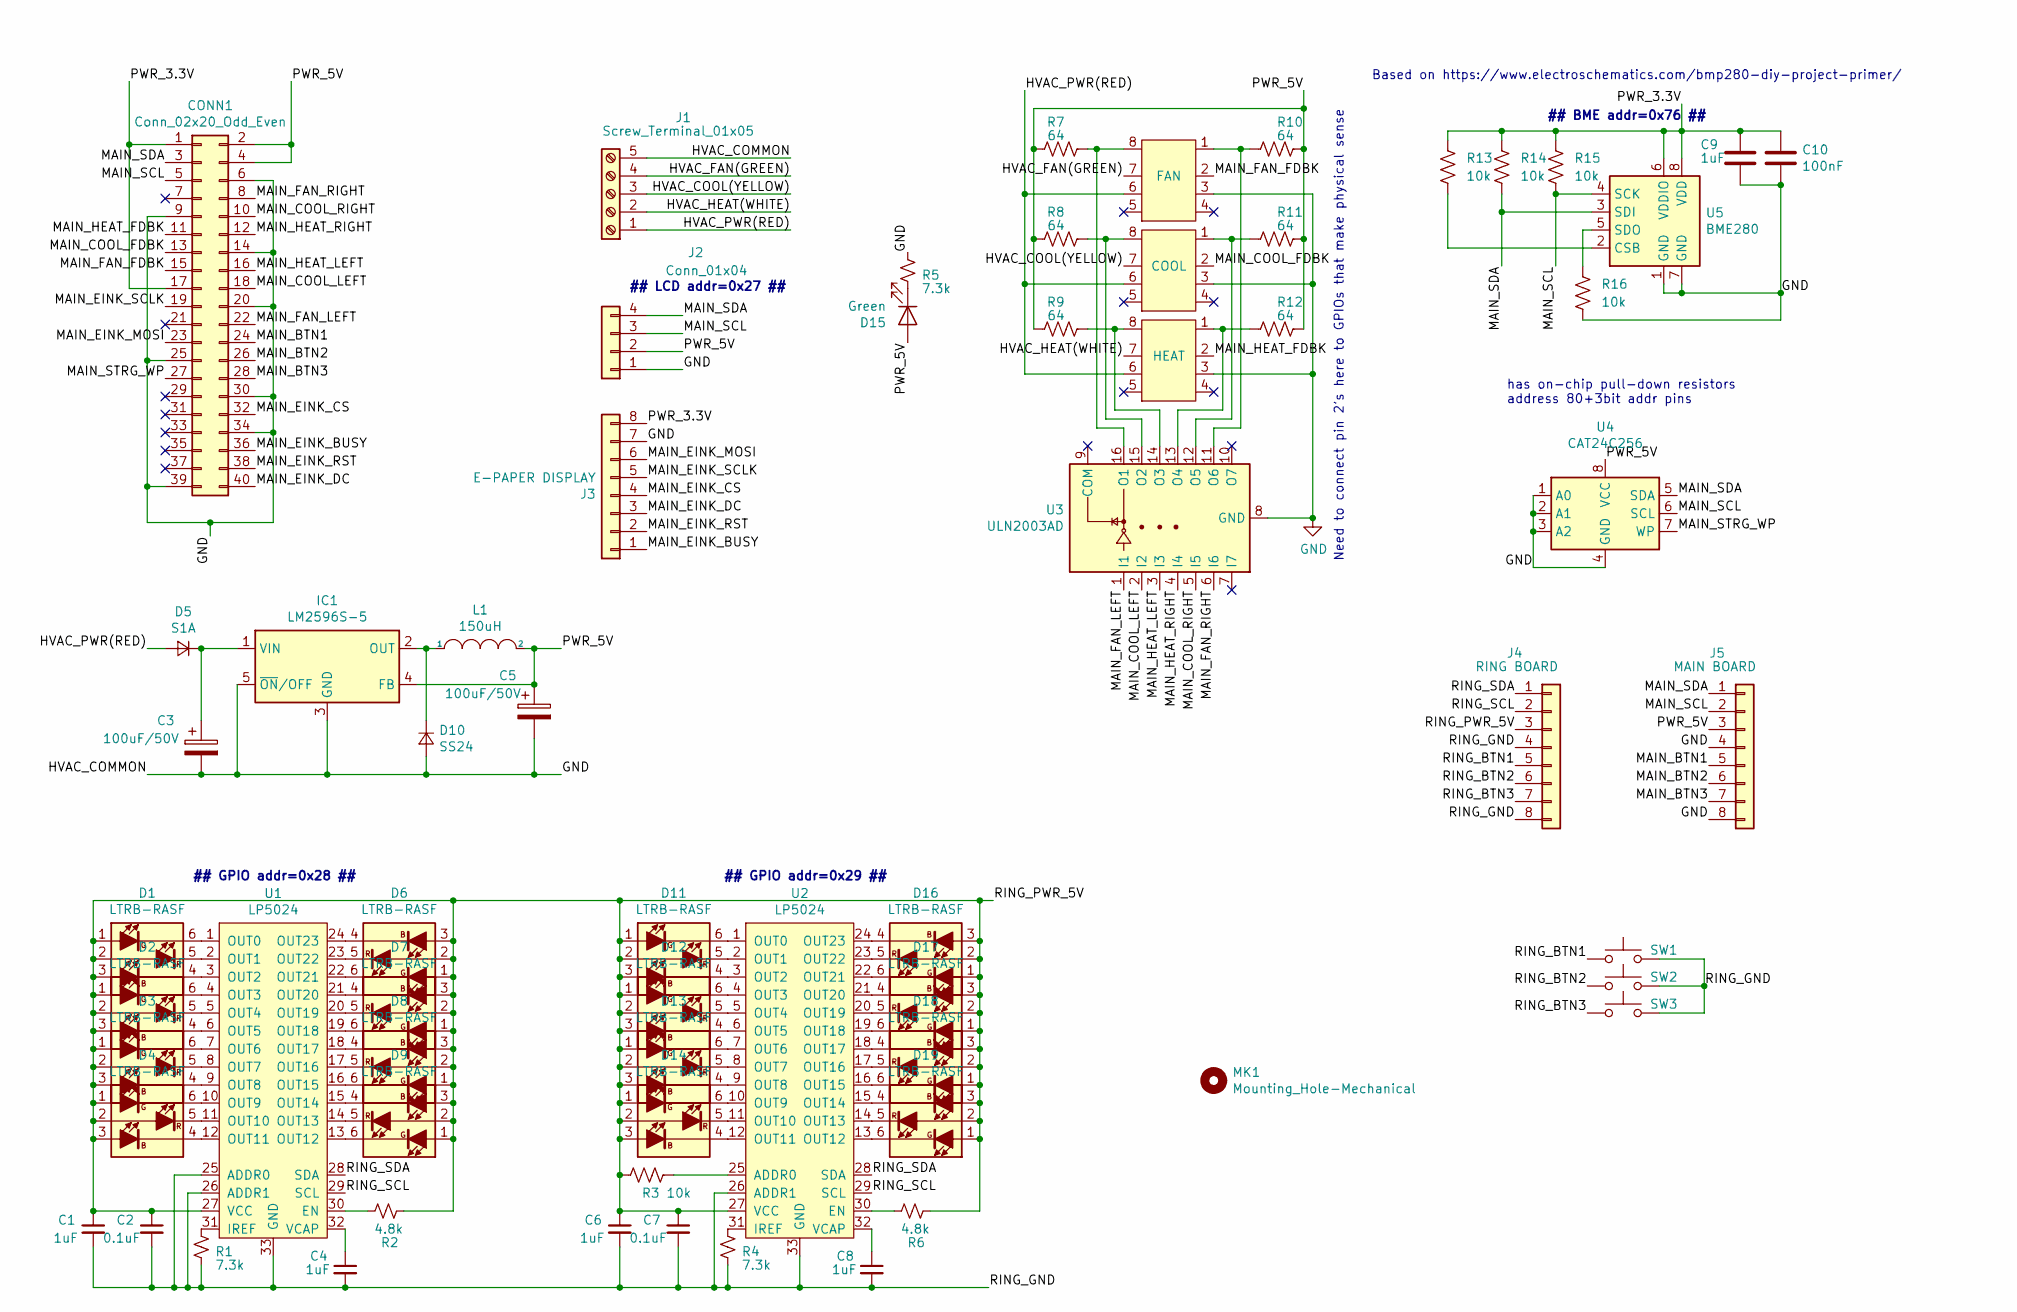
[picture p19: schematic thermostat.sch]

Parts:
C1, C4, C6, C8: 1uF; C_0805_2012Metric; Mouser 80-C0805C105M8RAUTO
C2, C7: 0.1uF; C_0805_2012Metric; Mouser 80-C0805X104K5R3316
C3, C5: 100uF/50V; C_Elec_8x10.2; MPN 667-EEE-FP1H101AV; Mouser 667-EEE-FP1H101AV
C9: 1uF; C_0805_2012Metric; MPN 80-C0805C105M8RAUTO; Mouser 80-C0805C105M8RAUTO
C10: 100nF; C_0805_2012Metric; MPN 80-C0805X104K5R3316; Mouser 80-C0805X104K5R3316
CONN1: Conn_02x20_Odd_Even; PinSocket_2x20_P2.54mm_Vertical; MPN 485-2243; Mouser 485-2243
D1, D2, D3, D4, D6, D7, D8, D9, D11, D12, D13, D14, D16, D17, D18, D19: LTRB-RASF; SOT-23-6; Mouser 720-LTRBRASFA7231
D5: S1A; D_SOD-123F; MPN 512-US1AFA; Mouser 512-US1AFA
D10: SS24; D_SMB; MPN 625-SS24-E3; Mouser 625-SS24-E3
D15: Green; LED_0805_2012Metric; MPN 710-150080GS75000; Mouser 710-150080GS75000
IC1: LM2596S-5; TO-263-5_TabPin3; MPN 926-LM2596S-5.0/NOPB; Mouser 926-LM2596S-5.0/NOPB
J1: Screw_Terminal_01x05; CUI_TB004-508-05BE; MPN 490-TB004-508-05BE; Mouser 490-TB004-508-05BE
J2: Conn_01x04; PinHeader_1x04_P2.54mm_Vertical
J3: E-PAPER DISPLAY; PinHeader_1x08_P2.54mm_Vertical
J4: RING BOARD; PinHeader_1x08_P2.54mm_Vertical
J5: MAIN BOARD; PinHeader_1x08_P2.54mm_Vertical
L1: 150uH; L_Wuerth_WE-PD-Typ-M-Typ-S; MPN 710-7447773151; Mouser 710-7447773151
MK1: Mounting_Hole-Mechanical; oshw-logo-8_silkscreen-front_8mm
R1, R4, R5: 7.3k; R_0805_2012Metric; Mouser 667-ERJ-PB6B7321V
R2, R6: 4.8k; R_0805_2012Metric; Mouser 667-ERJ-PB3B4751V
R3, R13, R14, R15, R16: 10k; R_0805_2012Metric; MPN 667-ERJ-PB6B1002V; Mouser 667-ERJ-PB6B1002V
R7, R8, R9, R10, R11, R12: 64; R_0805_2012Metric; MPN 667-ERJ-P06F64R9V; Mouser 667-ERJ-P06F64R9V
RELAY1: FAN; AGQ210A03; MPN 769-AGQ210A03Z; Mouser 769-AGQ210A03Z
RELAY2: COOL; AGQ210A03; MPN 769-AGQ210A03Z; Mouser 769-AGQ210A03Z
RELAY3: HEAT; AGQ210A03; MPN 769-AGQ210A03Z; Mouser 769-AGQ210A03Z
SW1, SW2, SW3: Button; SW_SPST_EVPBF; MPN 667-EVP-BFAC1A000; Mouser 667-EVP-BFAC1A000
U1, U2: LP5024; QFN-32-1EP_4x4mm_P0.4mm_EP2.9x2.9mm; Mouser 595-LP5024RSMR
U3: ULN2003AD; SOIC-16_3.9x9.9mm_P1.27mm; Mouser 595-ULN2003AD
U4: CAT24C256; SOIC-8-1EP_3.9x4.9mm_P1.27mm_EP2.29x3mm; Mouser 698-CAT24C256WI-GT3
U5: BME280; Bosch_LGA-8_2.5x2.5mm_P0.65mm_ClockwisePinNumbering; MPN 262-BME280; Mouser 262-BME280

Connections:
/HVAC_COOL(YELLOW): J1.3, RELAY2.7
/HVAC_FAN(GREEN): J1.4, RELAY1.7
/HVAC_HEAT(WHITE): J1.2, RELAY3.7
/HVAC_PWR(RED): D5.2 (A), J1.1, RELAY1.6, RELAY2.6, RELAY3.6
/MAIN_BTN1: CONN1.24, J5.5
/MAIN_BTN2: CONN1.26, J5.6
/MAIN_BTN3: CONN1.28, J5.7
/MAIN_COOL_FDBK: CONN1.13, RELAY2.2
/MAIN_COOL_LEFT: CONN1.18, U3.2 (I2)
/MAIN_COOL_RIGHT: CONN1.10, U3.5 (I5)
/MAIN_EINK_BUSY: CONN1.36, J3.1
/MAIN_EINK_CS: CONN1.32, J3.4
/MAIN_EINK_DC: CONN1.40, J3.3
/MAIN_EINK_MOSI: CONN1.23, J3.6
/MAIN_EINK_RST: CONN1.38, J3.2
/MAIN_EINK_SCLK: CONN1.19, J3.5
/MAIN_FAN_FDBK: CONN1.15, RELAY1.2
/MAIN_FAN_LEFT: CONN1.22, U3.1 (I1)
/MAIN_FAN_RIGHT: CONN1.8, U3.6 (I6)
/MAIN_HEAT_FDBK: CONN1.11, RELAY3.2
/MAIN_HEAT_LEFT: CONN1.16, U3.3 (I3)
/MAIN_HEAT_RIGHT: CONN1.12, U3.4 (I4)
/MAIN_SCL: CONN1.5, J2.3, J5.2, R15.2, U4.6 (SCL), U5.4 (SCK)
/MAIN_SDA: CONN1.3, J2.4, J5.1, R14.2, U4.5 (SDA), U5.3 (SDI)
/MAIN_STRG_WP: CONN1.27, U4.7 (WP)
/PWR_3.3V: C9.1, C10.1, CONN1.1, CONN1.17, J3.8, R13.1, R14.1, R15.1, U5.6 (VDDIO), U5.8 (VDD)
/PWR_5V: C5.1, CONN1.2, CONN1.4, D15.2 (A), IC1.4 (FB), J2.2, J5.3, L1.2, R7.1, R8.1, R9.1, R10.2, R11.2, R12.2, U4.8 (VCC)
/RING_BTN1: J4.5, SW1.1
/RING_BTN2: J4.6, SW2.1
/RING_BTN3: J4.7, SW3.1
/RING_GND: C1.2, C2.2, C4.2, C6.2, C7.2, C8.2, J4.4, J4.8, R1.2, R4.2, SW1.2, SW2.2, SW3.2, U1.25 (ADDR0), U1.26 (ADDR1), U1.33 (GND), U2.26 (ADDR1), U2.33 (GND)
/RING_PWR_5V: C1.1, C2.1, C6.1, C7.1, D1.1 (AG), D1.2 (AR), D1.3 (AB), D2.1 (AG), D2.2 (AR), D2.3 (AB), D3.1 (AG), D3.2 (AR), D3.3 (AB), D4.1 (AG), D4.2 (AR), D4.3 (AB), D6.1 (AG), D6.2 (AR), D6.3 (AB), D7.1 (AG), D7.2 (AR), D7.3 (AB), D8.1 (AG), D8.2 (AR), D8.3 (AB), D9.1 (AG), D9.2 (AR), D9.3 (AB), D11.1 (AG), D11.2 (AR), D11.3 (AB), D12.1 (AG), D12.2 (AR), D12.3 (AB), D13.1 (AG), D13.2 (AR), D13.3 (AB), D14.1 (AG), D14.2 (AR), D14.3 (AB), D16.1 (AG), D16.2 (AR), D16.3 (AB), D17.1 (AG), D17.2 (AR), D17.3 (AB), D18.1 (AG), D18.2 (AR), D18.3 (AB), D19.1 (AG), D19.2 (AR), D19.3 (AB), J4.3, R2.2, R3.1, R6.2, U1.27 (VCC), U2.27 (VCC)
/RING_SCL: J4.2, U1.29 (SCL), U2.29 (SCL)
/RING_SDA: J4.1, U1.28 (SDA), U2.28 (SDA)
GND: C3.2, C5.2, C9.2, C10.2, CONN1.6, CONN1.9, CONN1.14, CONN1.20, CONN1.25, CONN1.30, CONN1.34, CONN1.39, D10.2 (A), IC1.3 (GND), IC1.5 (~ON~/OFF), J1.5, J2.1, J3.7, J5.4, J5.8, R5.1, R16.2, RELAY1.3, RELAY2.3, RELAY3.3, U3.8 (GND), U4.1 (A0), U4.2 (A1), U4.3 (A2), U4.4 (GND), U5.1 (GND), U5.7 (GND)
unnamed: C3.1, D5.1 (K), IC1.1 (VIN)
unnamed: C4.1, U1.32 (VCAP)
unnamed: C8.1, U2.32 (VCAP)
unnamed: D1.4 (KB), U1.3 (OUT2)
unnamed: D1.5 (KR), U1.2 (OUT1)
unnamed: D1.6 (KG), U1.1 (OUT0)
unnamed: D2.4 (KB), U1.6 (OUT5)
unnamed: D2.5 (KR), U1.5 (OUT4)
unnamed: D2.6 (KG), U1.4 (OUT3)
unnamed: D3.4 (KB), U1.9 (OUT8)
unnamed: D3.5 (KR), U1.8 (OUT7)
unnamed: D3.6 (KG), U1.7 (OUT6)
unnamed: D4.4 (KB), U1.12 (OUT11)
unnamed: D4.5 (KR), U1.11 (OUT10)
unnamed: D4.6 (KG), U1.10 (OUT9)
unnamed: D6.4 (KB), U1.24 (OUT23)
unnamed: D6.5 (KR), U1.23 (OUT22)
unnamed: D6.6 (KG), U1.22 (OUT21)
unnamed: D7.4 (KB), U1.21 (OUT20)
unnamed: D7.5 (KR), U1.20 (OUT19)
unnamed: D7.6 (KG), U1.19 (OUT18)
unnamed: D8.4 (KB), U1.18 (OUT17)
unnamed: D8.5 (KR), U1.17 (OUT16)
unnamed: D8.6 (KG), U1.16 (OUT15)
unnamed: D9.4 (KB), U1.15 (OUT14)
unnamed: D9.5 (KR), U1.14 (OUT13)
unnamed: D9.6 (KG), U1.13 (OUT12)
unnamed: D10.1 (K), IC1.2 (OUT), L1.1
unnamed: D11.4 (KB), U2.3 (OUT2)
unnamed: D11.5 (KR), U2.2 (OUT1)
unnamed: D11.6 (KG), U2.1 (OUT0)
unnamed: D12.4 (KB), U2.6 (OUT5)
unnamed: D12.5 (KR), U2.5 (OUT4)
unnamed: D12.6 (KG), U2.4 (OUT3)
unnamed: D13.4 (KB), U2.9 (OUT8)
unnamed: D13.5 (KR), U2.8 (OUT7)
unnamed: D13.6 (KG), U2.7 (OUT6)
unnamed: D14.4 (KB), U2.12 (OUT11)
unnamed: D14.5 (KR), U2.11 (OUT10)
unnamed: D14.6 (KG), U2.10 (OUT9)
unnamed: D15.1 (K), R5.2
unnamed: D16.4 (KB), U2.24 (OUT23)
unnamed: D16.5 (KR), U2.23 (OUT22)
unnamed: D16.6 (KG), U2.22 (OUT21)
unnamed: D17.4 (KB), U2.21 (OUT20)
unnamed: D17.5 (KR), U2.20 (OUT19)
unnamed: D17.6 (KG), U2.19 (OUT18)
unnamed: D18.4 (KB), U2.18 (OUT17)
unnamed: D18.5 (KR), U2.17 (OUT16)
unnamed: D18.6 (KG), U2.16 (OUT15)
unnamed: D19.4 (KB), U2.15 (OUT14)
unnamed: D19.5 (KR), U2.14 (OUT13)
unnamed: D19.6 (KG), U2.13 (OUT12)
unnamed: R1.1, U1.31 (IREF)
unnamed: R2.1, U1.30 (EN)
unnamed: R3.2, U2.25 (ADDR0)
unnamed: R4.1, U2.31 (IREF)
unnamed: R6.1, U2.30 (EN)
unnamed: R7.2, RELAY1.8, U3.16 (O1)
unnamed: R8.2, RELAY2.8, U3.15 (O2)
unnamed: R9.2, RELAY3.8, U3.14 (O3)
unnamed: R10.1, RELAY1.1, U3.11 (O6)
unnamed: R11.1, RELAY2.1, U3.12 (O5)
unnamed: R12.1, RELAY3.1, U3.13 (O4)
unnamed: R13.2, U5.2 (CSB)
unnamed: R16.1, U5.5 (SDO)

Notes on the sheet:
Based on https://www.electroschematics.com/bmp280-diy-project-primer/
## LCD addr=0x27 ##
## BME addr=0x76 ##
Need to connect pin 2’s here to GPIOs that make physical sense
## GPIO addr=0x28 ##
## GPIO addr=0x29 ##
has on-chip pull-down resistors address 80+3bit addr pins

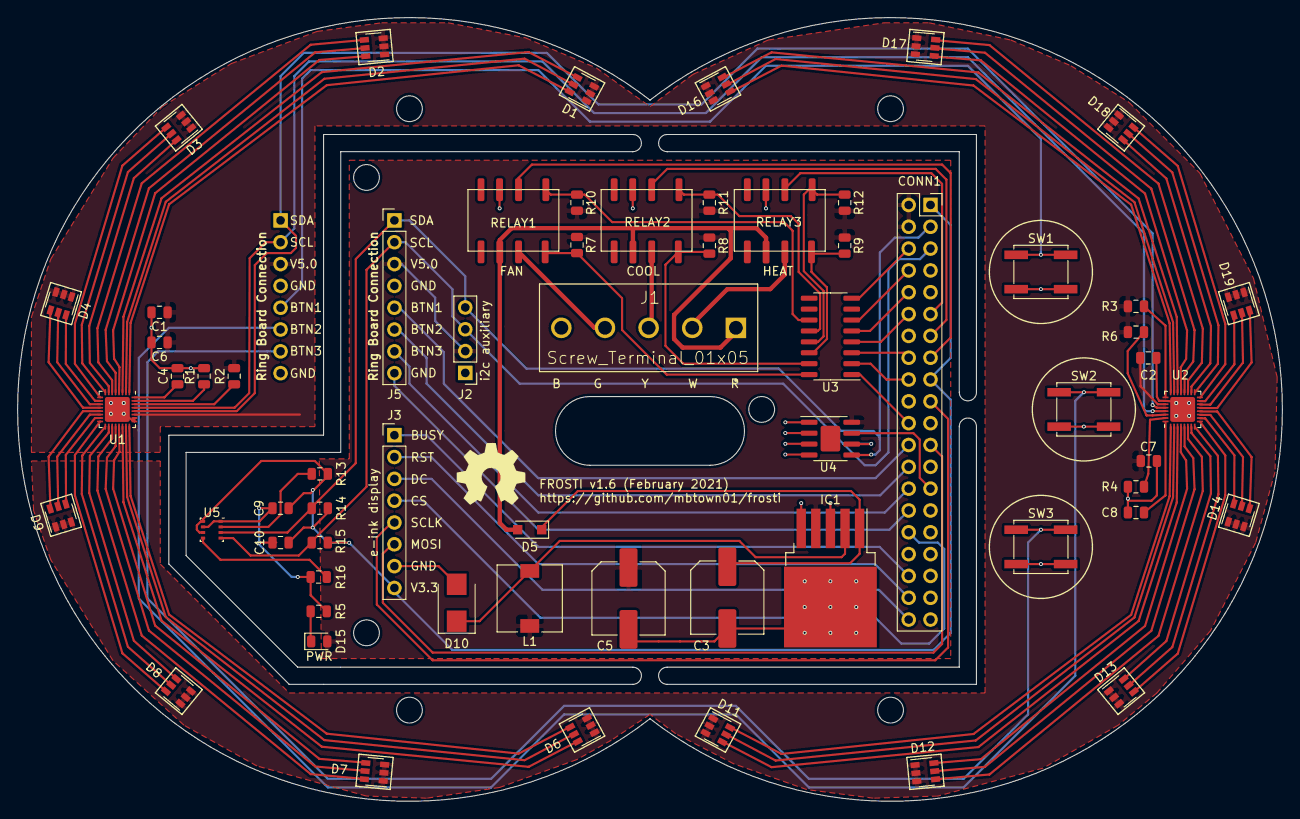
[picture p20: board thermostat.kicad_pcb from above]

Board: 2 copper layers, 147.2 x 91.2 mm, 65 parts (1 on the bottom side), 101 nets.

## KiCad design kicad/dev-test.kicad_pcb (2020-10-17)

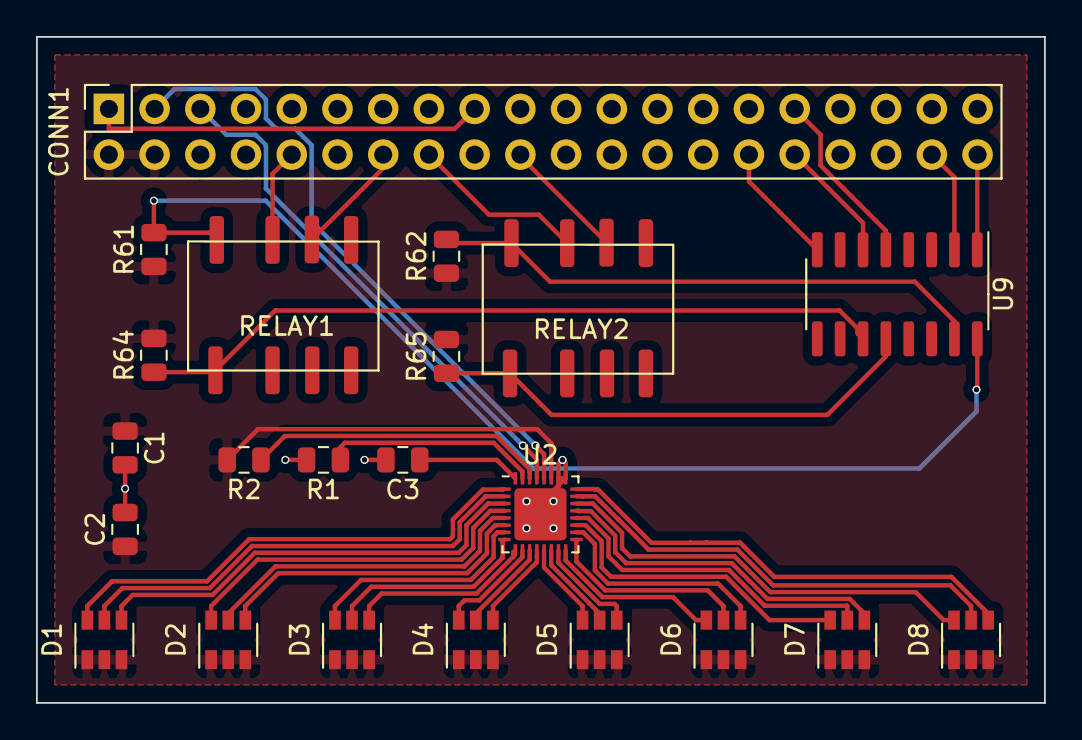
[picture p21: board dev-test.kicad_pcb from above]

Board: 2 copper layers, 56.0 x 37.0 mm, 22 parts (0 on the bottom side), 42 nets.

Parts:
C1, C3: 1uF; C_0805_2012Metric
C2: 0.1uF; C_0805_2012Metric
CONN1: Conn_02x20_Odd_Even; PinSocket_2x20_P2.54mm_Vertical
D1, D2, D3, D4, D5, D6, D7, D8: LTRB-RASF; SOT-23-6
R1: 7.3k; R_0805_2012Metric
R2: 4.8k; R_0805_2012Metric
R61, R62, R64, R65: 64; R_0805_2012Metric
RELAY1: FAN; AGQ210A03
RELAY2: HEAT; AGQ210A03
U2: LP5024; QFN-32-1EP_4x4mm_P0.4mm_EP2.9x2.9mm
U9: ULN2003AD; SOIC-16_3.9x9.9mm_P1.27mm

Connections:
/GPIO2(SDA1): CONN1.3, U2.28
/GPIO3(SCL1): CONN1.5, U2.29
/GPIO6: CONN1.31, U9.5
/GPIO12(PWM0): CONN1.32, U9.6
/GPIO15(RXD0): CONN1.10, RELAY1.7
/GPIO20(SPI1_MOSI): CONN1.38, U9.2
/GPIO21(SPI1_SCK): CONN1.40, U9.1
/GPIO23(GEN4): CONN1.16, RELAY2.7
/PWR_3.3V: CONN1.1, CONN1.17
/PWR_5V: C1.1, C2.1, CONN1.2, CONN1.4, D1.1, D1.2, D1.3, D2.1, D2.2, D2.3, D3.1, D3.2, D3.3, D4.1, D4.2, D4.3, D5.1, D5.2, D5.3, D6.1, D6.2, D6.3, D7.1, D7.2, D7.3, D8.1, D8.2, D8.3, R2.2, R61.1, R62.1, R64.2, R65.2, U2.27
GND: C1.2, C2.2, C3.2, CONN1.6, CONN1.9, CONN1.14, CONN1.20, CONN1.25, CONN1.30, CONN1.34, CONN1.39, R1.2, RELAY1.6, RELAY2.6, U2.25, U2.26, U2.33, U9.8
unnamed: C3.1, U2.32
unnamed: D1.4, U2.3
unnamed: D1.5, U2.2
unnamed: D1.6, U2.1
unnamed: D2.4, U2.6
unnamed: D2.5, U2.5
unnamed: D2.6, U2.4
unnamed: D3.4, U2.9
unnamed: D3.5, U2.8
unnamed: D3.6, U2.7
unnamed: D4.4, U2.12
unnamed: D4.5, U2.11
unnamed: D4.6, U2.10
unnamed: D5.4, U2.15
unnamed: D5.5, U2.14
unnamed: D5.6, U2.13
unnamed: D6.4, U2.18
unnamed: D6.5, U2.17
unnamed: D6.6, U2.16
unnamed: D7.4, U2.21
unnamed: D7.5, U2.20
unnamed: D7.6, U2.19
unnamed: D8.4, U2.24
unnamed: D8.5, U2.23
unnamed: D8.6, U2.22
unnamed: R1.1, U2.31
unnamed: R2.1, U2.30
unnamed: R61.2, RELAY1.8, U9.16
unnamed: R62.2, RELAY2.8, U9.15
unnamed: R64.1, RELAY1.1, U9.11
unnamed: R65.1, RELAY2.1, U9.12

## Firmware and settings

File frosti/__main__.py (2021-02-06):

from os import path, system, getpid
import yaml
import argparse
from subprocess import run

from frosti.logging import log, setupLogging, handleException
from frosti.core import EventBus, ServiceProvider
from frosti.services import ApiDataBrokerService, \
    GoGriddyPriceCheckService, OrmManagementService, ThermostatService, \
    OrmStateCaptureService, UserInterfaceService, EnvironmentSamplingService, \
    RelayManagementService, DashApplicationService
from frosti.core.events import SettingsChangedEvent
from frosti.hardware import hardware_init


class RootDriver(ServiceProvider):

    def __init__(self):
        super().__init__()

        parser = argparse.ArgumentParser(
            description='FROSTI main process')
        parser.add_argument(
            '--hardware', choices=['v5', 'v6', 'auto'], default='auto',
            help='Pick the underlying hardware supporting operations')
        parser.add_argument(
            '--diagnostics', default=False, action='store_true',
            help='Run hardware diagnostics and exit')
        parser.add_argument(
            '--watchdog', default=None, type=int,
            help='Call systemd-notify every *n* seconds')
        self.__args = parser.parse_args()

    def __detectHardware(self):
        from board import SDA, SCL
        from busio import I2C
        i2c = I2C(SCL, SDA)
        results = i2c.scan()

        # Hardware v5 the two 5024 chips at 0x28 and 0x29
        if 0x28 in results and 0x29 in results:
            return "v6"

        raise RuntimeError("We just don't support hardware older than v5")

    def __getYamlConfigData(self):
        localPath = path.realpath(__file__)

        searchOrder = (
            path.expanduser('~/.frosti.yaml'),
            '/etc/frosti.yaml',
            path.abspath(
                path.dirname(localPath) + '/../etc/frosti.yaml')
        )

        for fileName in searchOrder:
            if path.exists(fileName):
                log.info(f"Configuration coming from {fileName}")
                with open(fileName) as configFile:
                    return yaml.load(configFile, Loader=yaml.FullLoader)

        raise RuntimeError("Couldn't not find a frosti.yaml config file")

    def start(self):
        import RPi.GPIO as GPIO

        GPIO.setmode(GPIO.BCM)
        setupLogging()

        self.__eventBus = EventBus()
        self.installService(EventBus, self.__eventBus)

        ormManagementService = OrmManagementService()
        ormManagementService.setServiceProvider(self)
        self.installService(
            OrmManagementService, ormManagementService)

        ormStateCaptureService = OrmStateCaptureService()
        ormStateCaptureService.setServiceProvider(self)
        self.installService(
            OrmStateCaptureService, ormStateCaptureService)

        # Put all the event handlers together
        configData = self.__getYamlConfigData()
        apiDataBrokerService = ApiDataBrokerService()
        apiDataBrokerService.setServiceProvider(self)
        apiDataBrokerService.setConfig(configData['config'])
        apiDataBrokerService.setPrograms(configData['programs'])
        apiDataBrokerService.setSchedules(configData['schedules'])

        thermostatService = ThermostatService()
        thermostatService.setServiceProvider(self)
        self.installService(ThermostatService, thermostatService)

        if self.__args.hardware == 'auto':
            self.__args.hardware = self.__detectHardware()
            log.info(f"Starting FROSTI on hardware {self.__args.hardware}")

        hardware_init(self, self.__args.hardware)

        # Setup the power price handler after the other services have
        # been created so they get the first power events
        try:
            priceChecker = GoGriddyPriceCheckService()
            priceChecker.setServiceProvider(self)
        except ConnectionError:
            log.warning("Unable to reach GoGriddy")

        dashApplicationService = DashApplicationService()
        dashApplicationService.setServiceProvider(self)

        # If the watchdog has been requested and the binary exists, install a
        # recurring timer to 'pet the dog'
        if self.__args.watchdog is not None:
            if path.exists('/usr/bin/systemd-notify'):
                def watchdogTimerHandler():
                    return run(['/usr/bin/systemd-notify',
                                '--pid', f"{getpid()}",
                                'WATCHDOG=1'])

                log.info(
                    f"Watchdog update process every {self.__args.watchdog}s")
                self.__eventBus.installTimer(
                    frequency=self.__args.watchdog,
                    handler=watchdogTimerHandler)

        try:
            log.info('Entering into standard operation')
            self.__eventBus.fireEvent(SettingsChangedEvent())
            self.__eventBus.exec()
        finally:
            GPIO.cleanup()


if __name__ == '__main__':
    log.info('Starting thermostat main thread')

    # import RPi.GPIO as GPIO
    # import smbus

    # GPIO.setmode(GPIO.BCM)

    # addr = 0x50
    # bus = smbus.SMBus(1)

    # # write protect for EEPROM is GPIO0 (pin 27)
    # def write(memory_address, data):
    #     cmd = memory_address >> 8
    #     bytes = [memory_address & 0xff] + data
    #     print(f"writing to {memory_address} len={len(data)}")
    #     return bus.write_i2c_block_data(addr, cmd, bytes)

    # def read(memory_address, count):
    #     bus.write_byte(addr, memory_address >> 8)
    #     bus.write_byte(addr, memory_address & 0xff)
    #     return list(bus.read_byte(addr) for _ in range(count))

    try:
        rootDriver = RootDriver()
        rootDriver.start()
    except:
        handleException("Main entry point")

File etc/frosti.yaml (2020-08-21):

# In the absence of a setting being in the postgres database, these are the
# default values chosen at initialization time.  Once in the database, they
# must be changed there
config:
  # Temperature delta (degF) above comfortMax where COOL kicks in AND delta 
  # below comfortMin where HEAT kicks in
  thermostat.delta: 1.0
  # Amount of time (seconds) to continue running the fan after a HEAT or
  # COOL cycle has ended
  thermostat.fanRunoutDuration: 15
  # Default timezone 
  thermostat.timezone: "America/Chicago"
  # For the three environment sensors (temperature, pressure, humidity), 
  # apply translate and scale so that for any sensor reading 'x', the actual
  # reading is scale*x + translate
  environment.temperature.translate: 0.0
  environment.temperature.scale: 1.0
  environment.humidity.translate: 0.0
  environment.humidity.scale: 1.0
  environment.pressure.translate: 0.0
  environment.pressure.scale: 1.0
  # How long (seconds) to leave the backlight on before timing out
  ui.backlightTimeout: 10
  # Default gogriddy membership info that should be removed in a final release
  # but is required to call the Griddy web API
  gogriddy.meterId: "1008901023809085840100"
  gogriddy.memberId: "32795"
  gogriddy.settlementPoint: "LZ_HOUSTON"
  
programs:
  overnight: { comfortMin: 68, comfortMax: 88 }
  home:
    comfortMin: 70
    comfortMax: 83
    priceOverrides:
      - { price: 0.10, comfortMax: 85 }
      - { price: 0.20, comfortMax: 88 }
      - { price: 0.40, comfortMax: 99 }
  away:
    comfortMin: 64
    comfortMax: 86
    priceOverrides:
      - { price: 0.25, comfortMax: 99 }

schedules:
  work week:
    days: [0, 1, 2, 3, 4]
    times:
      - { hour: 8, minute: 0, program: home }
      - { hour: 20, minute: 0, program: overnight }
  weekend:
    days: [5, 6]
    times:
      - { hour: 8, minute: 0, program: home }
      - { hour: 20, minute: 0, program: overnight }

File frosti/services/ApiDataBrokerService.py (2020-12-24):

from flask import Flask, Response, request, abort, send_file
from flask_restx import Resource, Api, fields
from flask_cors import CORS
from functools import wraps
from threading import Thread
from random import getrandbits
import uuid
import json
from io import BytesIO

from .ThermostatService import ThermostatService
from .OrmManagementService import OrmManagementService
from frosti.logging import log, handleException
from frosti.core import ServiceProvider, ServiceConsumer, EventBus, \
    ThermostatState
from frosti.core.events import ThermostatStateChangedEvent, SensorDataChangedEvent
from frosti.core.orm import OrmConfig, OrmProgram, OrmSchedule, \
    OrmPriceOverride, OrmScheduleDay, OrmScheduleTime
from frosti.services.UserInterfaceService import UserInterfaceService

VALID_API_KEYS = list()

# FLASK_APP = Flask(__name__, static_url_path='')
# FLASK_RESTX_API = Api(FLASK_APP)
# FLASK_RESTX_NS = FLASK_RESTX_API.namespace(
#     "api/v2", description="Thermostat operations")

# Some thoughts on how to do this well...
# We could refactor service providers into a module-level thing similiar
# to the way logging works.  All eyes can then point to a single service
# provider and classes could either point requests for services there or
# could "subscribe".  Not sure what that would look like, but it would clean
# up the prob below of having ephemeral classes created that need services!


def require_appkey(method):
    """ Decorator for identifying an API method that requets a key """
    @wraps(method)
    def decoratedMethod(*args, **kwargs):
        if request.args.get('key', 'none') in VALID_API_KEYS:
            return method(*args, **kwargs)
        abort(401)

    return decoratedMethod


# @FLASK_RESTX_NS.route("/test/<string:resourceId>")
# @FLASK_RESTX_API.doc(
#     responses={404: "test not found"}, params={"resourceId": "test ID"})
# class Test(Resource):

#     def __init__(self, api=None, *args, **kwargs):
#         super().__init__(api, *args, **kwargs)

#     @FLASK_RESTX_API.doc(description="test description")
#     def get(self, resourceId):
#         debug('TEST get')
#         return [{'resourceId': 'test'}]

#     @FLASK_RESTX_API.doc(responses={204: "Todo deleted"})
#     def put(self, resource):
#         debug('PUT delete')


class ApiDataBrokerService(ServiceConsumer):
    """ Dedicated to responding to the REST API for the thermostat and
    brokering any necessary data/events.

    This service owns the Flask thread that is monitoring incoming requests.
    All web API requests are given to the main event thread for processing.
    """

    def __init__(self):
        self.__flaskApp = Flask(__name__, static_url_path='')
        self.__flaskApp.add_url_rule(
            '/api/v1/status', view_func=self.__apiStatus, methods=['GET'])

        self.__flaskApp.add_url_rule(
            '/api/v1/config', view_func=self.__apiConfig,
            methods=['GET', 'POST', 'PUT', 'PATCH', 'DELETE'])
        self.__flaskApp.add_url_rule(
            '/api/v1/config/<name>', view_func=self.__apiConfig,
            methods=['GET', 'PUT', 'PATCH', 'DELETE'])
        self.__flaskApp.add_url_rule(
            '/api/v1/programs', view_func=self.__apiPrograms,
            methods=['GET', 'POST', 'PUT', 'PATCH', 'DELETE'])
        self.__flaskApp.add_url_rule(
            '/api/v1/programs/<name>', view_func=self.__apiPrograms,
            methods=['GET', 'PUT', 'PATCH', 'DELETE'])
        self.__flaskApp.add_url_rule(
            '/api/v1/schedules', view_func=self.__apiSchedules,
            methods=['GET', 'POST', 'PUT', 'PATCH', 'DELETE'])
        self.__flaskApp.add_url_rule(
            '/api/v1/schedules/<name>', view_func=self.__apiSchedules,
            methods=['GET', 'PUT', 'PATCH', 'DELETE'])
        self.__flaskApp.add_url_rule(
            '/api/v1/actions', view_func=self.__apiActions,
            methods=['GET'])
        self.__flaskApp.add_url_rule(
            '/api/v1/actions/<name>', view_func=self.__apiActions,
            methods=['POST'])
        self.__flaskApp.add_url_rule(
            '/api/v1/display', view_func=self.__apiCurrentDisplay,
            methods=['GET'])

        self.__flaskApp.add_url_rule(
            '/api/v1/action/stop',
            view_func=self.__apiActionStop, methods=['POST'])
        self.__flaskApp.add_url_rule(
            '/api/v1/action/nextMode',
            view_func=self.__apiActionNextMode, methods=['POST'])
        self.__flaskApp.add_url_rule(
            '/api/v1/action/changeComfort',
            view_func=self.__apiActionChangeComfort, methods=['POST'])

        self.__cors = CORS(self.__flaskApp)

        self.__flaskThread = Thread(
            target=self.__flaskEntryPoint,
            name='Flask Driver')
        self.__flaskThread.daemon = True
        self.__flaskThread.start()

        self.__lastState = ThermostatState.OFF
        self.__lastSensorData = None
        self.__sessionApiKey = f"{getrandbits(256):x}"
        VALID_API_KEYS.append(self.__sessionApiKey)

    def setServiceProvider(self, provider: ServiceProvider):
        super().setServiceProvider(provider)

        self.__eventBus = self._getService(EventBus)
        self.__eventBus.installEventHandler(
            SensorDataChangedEvent, self.__processSensorDataChanged)
        self.__eventBus.installEventHandler(
            ThermostatStateChangedEvent, self.__processThermostatStateChanged)

    @property
    def sessionApiKey(self):
        return self.__sessionApiKey

    def __processThermostatStateChanged(
            self, event: ThermostatStateChangedEvent):
        self.__lastState = event.state

    def __processSensorDataChanged(self, event: SensorDataChangedEvent):
        self.__lastSensorData = event

    def getStatus(self):
        thermostatService = self._getService(ThermostatService)

        response = {
            'comfortMin': thermostatService.comfortMin,
            'comfortMax': thermostatService.comfortMax,
            'currentProgram': thermostatService.currentProgramName,
            'isInPriceOverride': thermostatService.isInPriceOverride,
            'state': str(thermostatService.state),
            'mode': str(thermostatService.mode)
        }

        if self.__lastSensorData is not None:
            response['sensors'] = {
                'temperature': f"{self.__lastSensorData.temperature}",
                'pressure': f"{self.__lastSensorData.pressure}",
                'humidity': f"{self.__lastSensorData.humidity}",
            }

        return response

    def getConfig(self):
        ormManagementService = self._getService(OrmManagementService)

        results = ormManagementService.session.query(OrmConfig)
        return {a.name: a.value for a in results}

    def __upsertEntities(
            self, entityClass, updateMethod, data: dict, patch: bool):
        ormManagementService = self._getService(OrmManagementService)
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

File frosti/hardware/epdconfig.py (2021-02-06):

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

import os
import logging
import sys
import time


class RaspberryPi:
    # Pin definition for FROSTI
    RST_PIN = 14
    DC_PIN = 17
    CS_PIN = 4
    BUSY_PIN = 15

    def __init__(self):
        import spidev
        import RPi.GPIO

        self.GPIO = RPi.GPIO

        # SPI device, bus = 0, device = 0
        self.SPI = spidev.SpiDev(0, 0)

    def digital_write(self, pin, value):
        self.GPIO.output(pin, value)

    def digital_read(self, pin):
        return self.GPIO.input(pin)

    def delay_ms(self, delaytime):
        time.sleep(delaytime / 1000.0)

    def spi_writebyte(self, data):
        self.SPI.writebytes(data)

    def gpio_setup(self, rstPin: int, dcPin: int, csPin: int, busyPin: int):
        self.RST_PIN = rstPin
        self.DC_PIN = dcPin
        self.CS_PIN = csPin
        self.BUSY_PIN = busyPin

    def module_init(self):
        self.GPIO.setmode(self.GPIO.BCM)
        self.GPIO.setwarnings(False)
        self.GPIO.setup(self.RST_PIN, self.GPIO.OUT)
        self.GPIO.setup(self.DC_PIN, self.GPIO.OUT)
        self.GPIO.setup(self.CS_PIN, self.GPIO.OUT)
        self.GPIO.setup(self.BUSY_PIN, self.GPIO.IN)
        self.SPI.max_speed_hz = 4000000
        self.SPI.mode = 0b00
        return 0

    def module_exit(self):
        logging.debug("spi end")
        self.SPI.close()

        logging.debug("close 5V, Module enters 0 power consumption ...")
        self.GPIO.output(self.RST_PIN, 0)
        self.GPIO.output(self.DC_PIN, 0)

        self.GPIO.cleanup()


class JetsonNano:
    # Pin definition
    RST_PIN = 17
    DC_PIN = 25
    CS_PIN = 8
    BUSY_PIN = 24

    def __init__(self):
        import ctypes
        find_dirs = [
            os.path.dirname(os.path.realpath(__file__)),
            '/usr/local/lib',
            '/usr/lib',
        ]
        self.SPI = None
        for find_dir in find_dirs:
            so_filename = os.path.join(find_dir, 'sysfs_software_spi.so')
            if os.path.exists(so_filename):
                self.SPI = ctypes.cdll.LoadLibrary(so_filename)
                break
        if self.SPI is None:
            raise RuntimeError('Cannot find sysfs_software_spi.so')

        import Jetson.GPIO
        self.GPIO = Jetson.GPIO

    def digital_write(self, pin, value):
        self.GPIO.output(pin, value)

    def digital_read(self, pin):
        return self.GPIO.input(self.BUSY_PIN)

    def delay_ms(self, delaytime):
        time.sleep(delaytime / 1000.0)

    def spi_writebyte(self, data):
        self.SPI.SYSFS_software_spi_transfer(data[0])

    def gpio_setup(self, rstPin: int, dcPin: int, csPin: int, busyPin: int):
        self.RST_PIN = rstPin
        self.DC_PIN = dcPin
        self.CS_PIN = csPin
        self.BUSY_PIN = busyPin

    def module_init(self):
        self.GPIO.setmode(self.GPIO.BCM)
        self.GPIO.setwarnings(False)
        self.GPIO.setup(self.RST_PIN, self.GPIO.OUT)
        self.GPIO.setup(self.DC_PIN, self.GPIO.OUT)
        self.GPIO.setup(self.CS_PIN, self.GPIO.OUT)
        self.GPIO.setup(self.BUSY_PIN, self.GPIO.IN)
        self.SPI.SYSFS_software_spi_begin()
        return 0

    def module_exit(self):
        logging.debug("spi end")
        self.SPI.SYSFS_software_spi_end()

        logging.debug("close 5V, Module enters 0 power consumption ...")
        self.GPIO.output(self.RST_PIN, 0)
        self.GPIO.output(self.DC_PIN, 0)

        self.GPIO.cleanup()


# if os.path.exists('/sys/bus/platform/drivers/gpiomem-bcm2835'):
#     implementation = RaspberryPi()
# else:
#     implementation = JetsonNano()

# for func in [x for x in dir(implementation) if not x.startswith('_')]:
#     setattr(sys.modules[__name__], func, getattr(implementation, func))


### END OF FILE ###

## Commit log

2019-07-05 Enable pep8 linting, address issues
    [interfaces.py, physical.py, settings.py]
2019-07-15 first pass at LCD, not working
    [__main__.py, hardware.py]
2019-07-28 add temperature change keys
2019-08-18 some board changes, probably too small...
    [thermostat.kicad_pcb, thermostat.sch]
2019-08-20 screw terminals
    [thermostat.sch]
2019-08-21 First take at the bigger board
    [thermostat.kicad_pcb, thermostat.sch]
2019-08-26 Almost ready for ethernet header
    [PoE Circuit.sch, thermostat.kicad_pcb, thermostat.sch]
2019-08-28 Ready for checkout and routing
    [thermostat.kicad_pcb, thermostat.sch]
2019-08-30 Re-arrange board; still need measurements
    [thermostat.kicad_pcb, thermostat.sch]
2019-08-31 more updates, backstop before 24v conversation
    [thermostat.kicad_pcb, thermostat.sch]
2019-09-01 migrate to 24v conversion
    [thermostat.kicad_pcb, thermostat.sch]
2019-09-01 ready for pours and routing
    [thermostat.kicad_pcb, thermostat.sch]
2019-09-01 First full pour
    [thermostat.kicad_pcb, thermostat.sch]
2019-09-02 Larger power traces, ready for clean-up
    [thermostat.kicad_pcb, thermostat.sch]
2019-09-02 major clean-up complete
    [thermostat.kicad_pcb, thermostat.sch]
2019-09-02 BOM updated and SUBMITTED!!!
    [thermostat.sch]
2019-09-07 Updates for v1.1
    [thermostat.kicad_pcb, thermostat.sch]
2019-09-15 move screen from generic hardware, broke tests...
    [config.py, generics.py]
2019-09-19 updates to stage for travel
2019-09-21 working v1.0 board w/ modifications
2019-09-22 more cleanup; backlight still not working
    [__main__.py, generics.py, hardware.py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]
2019-09-27 Re-worked LCD display, fixed backlight
    [hardware.py]
2019-10-01 fix thermostat startup to _defaults issue
    [generics.py, hardware.py]
2019-10-04 refactor sensor events into one
2019-10-05 Refactor to event-based, still need to fix rpi
    [__main__.py, api.py, events.py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]
2019-10-06 more bug fixes in thermostat logic
    [events.py, generics.py]
2019-10-06 more cleanup, better testing an error handling
    [__main__.py, events.py, generics.py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]
2019-10-06 fix not firing status update
    [generics.py]
2019-10-11 even more fixed tests
    [generics.py]
2019-10-13 more test cleanup, resolve time on eventbus
    [api.py, events.py, generics.py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]
2019-12-15 Re-address issue #4, fix infinite open/close relay loopwq
    [hardware.py]
2019-12-15 Track relay toggled for ALL changes of the relay
2019-12-26 fix terminal display; del influx settings restore
    [influx.py, terminal.py]
2020-01-01 first pass at supercap circuit, still WIP
    [thermostat.sch]
2020-01-01 addition of bmp280
    [thermostat.sch]
2020-01-02 new symbol for transistor
    [thermostat.sch]
2020-01-03 Support for KiCad v5.14 libraries
    [thermostat.kicad_pcb, thermostat.sch]
2020-01-03 Updated ALL references to new library
    [thermostat.kicad_pcb, thermostat.sch]
2020-01-04 small change
    [thermostat.sch]
2020-01-04 ltc4041 overall design ready
    [thermostat.sch]
2020-01-04 ready to start routing
    [thermostat.kicad_pcb, thermostat.sch]
2020-01-06 almost routed
    [thermostat.kicad_pcb, thermostat.sch]
2020-01-06 forgot worksheet
    [sanity-check.xlsx]
2020-01-06 fully routed v2.0
    [thermostat.kicad_pcb, thermostat.sch]
2020-01-08 pre-routing of smaller version
    [thermostat.kicad_pcb, thermostat.sch]
2020-01-10 updates, close to thermostat v2.1
    [thermostat.kicad_pcb, thermostat.sch]
2020-01-10 passing v2.0 to MacroFab
    [thermostat.kicad_pcb, thermostat.sch]
2020-01-25 updates to BOM for mouser order
    [thermostat.kicad_pcb, thermostat.sch]
2020-01-27 add some freecad work
    [lcd.step, raspberrypizerov13.skp, thermostat.FCStd]
2020-01-27 CAD updates
    [thermostat.FCStd]
2020-02-16 sync changes
    [thermostat.kicad_pcb, thermostat.sch]
2020-02-16 board placed, ready for routing
    [thermostat.kicad_pcb, thermostat.sch]
2020-02-19 more updates
    [thermostat.kicad_pcb, thermostat.sch]
2020-02-22 more updates, i2c changes for breakout almost ready
    [thermostat.kicad_pcb, thermostat.sch]
2020-02-22 almost ready to route
    [thermostat.kicad_pcb, thermostat.sch]
2020-02-23 half routed
    [thermostat.kicad_pcb, thermostat.sch]
2020-02-23 Routing complete
    [thermostat.kicad_pcb]
2020-02-23 design v2.2 sent to fab
    [thermostat.kicad_pcb, thermostat.sch]
2020-02-23 change of silkscreen to reflect v3.0
    [thermostat.kicad_pcb]
2020-03-01 cleaner gitignore for kicad
    [sanity-check.xlsx]
2020-03-21 updates, cad broken
    [thermostat.kicad_pcb, thermostat.sch]
2020-03-28 add explicit hardware switch
2020-03-28 more container fixes; 1st pass at mcp23017
    [HardwareThermostatService_v2.py]
2020-03-29 fix stuck interrupt code
    [HardwareThermostatService_v2.py]
2020-03-29 Re-route 23017
    [thermostat.kicad_pcb, thermostat.sch]
2020-04-04 routed board
    [thermostat.kicad_pcb, thermostat.sch]
2020-04-04 final submission to OSH Park
    [thermostat.kicad_pcb]
2020-04-04 moved some diagram objects around
    [thermostat.sch]
2020-04-12 postgres now logging sensor readings
2020-04-20 initial led implementation; fix for EventBus loop
    [GoGriddyPriceCheckService.py, ThermostatService.py]
2020-04-22 move testing to the raspberry pi
2020-04-22 1st working hardware LED implementation
2020-04-23 container fixes for raspberrypi
2020-04-25 refactor imports, fix unit tests
    [ApiDataBrokerService.py, GoGriddyPriceCheckService.py, ThermostatService.py]
2020-04-26 more refactoring, update relay in schematic
    [thermostat.sch]
2020-04-28 bring back delayed relay toggles
2020-05-10 add i2c to ansible
2020-05-16 fixing v1 hardware and ansible
    [__main__.py]
2020-05-23 working button on the plugin
2020-05-28 new relay driver circuitry, layout needed
    [thermostat.kicad_pcb, thermostat.sch]
2020-07-26 add safeInvoke, fix some tests
    [ApiDataBrokerService.py, EnvironmentSamplingService.py, ThermostatService.py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]
2020-07-26 fix arm compose file
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2020-07-27 Update rpt.service; default arm to hardware 'auto'
2020-08-01 fix api testing, clean up old eventing
    [ApiDataBrokerService.py, ThermostatService.py]
2020-10-17 dev-test board to fab
    [dev-test.kicad_pcb, dev-test.sch, thermostat.sch]
2020-11-15 progress toward new design
    [thermostat.kicad_pcb, thermostat.sch]
2020-11-21 new board updates
    [thermostat.kicad_pcb, thermostat.sch]
2020-11-25 completely routed board
    [thermostat.kicad_pcb, thermostat.sch]
2020-11-25 2nd pass at hardware
    [thermostat.kicad_pcb, thermostat.sch]
2020-11-27 final tweaks for hardware v1.5
    [thermostat.kicad_pcb, thermostat.sch]
2020-12-02 update BOM for hardware v1.5
    [thermostat.sch]
2020-12-16 barely working web test bed for display
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2020-12-29 more clean-up of UI service and ring driver
2020-12-31 move out of container; fix Pillow install
    [OrmManagementService.py, UserInterfaceService.py]
2021-01-15 first completely wired v1.6 board
    [thermostat.kicad_pcb, thermostat.sch]
2021-01-15 cleaned up v1.6 board
    [thermostat.kicad_pcb]
2021-01-15 final v1.6 to the fab
    [thermostat.kicad_pcb, thermostat.sch]
2021-01-18 file cleanup
    [bottom.stl, button.stl, diffuser.stl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]
2021-01-18 fix for exception on chart draw
    [OrmStateCaptureService.py, UserInterfaceService.py, logging.py]
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
